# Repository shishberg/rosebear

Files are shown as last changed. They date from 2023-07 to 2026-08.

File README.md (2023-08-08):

# Rosebear

Rosebear is a 5x3+3 wireless split keyboard designed with [Ergogen](https://ergogen.xyz/). ZMK firmware is at https://github.com/shishberg/rosebear-zmk.

Thanks to [Ben Vallack](https://www.youtube.com/watch?v=M_VuXVErD6E) and [FlatFootFox](https://flatfootfox.com/ergogen-part5-kicad-firmware-assembly/) for the tutorials that made this even vaguely possible.

The assembled Rosebear split keyboard.

Screenshot of the Rosebear PCB in KiCad.

## Features
- Pretty aggressive stagger on the pinky column, and splay on pinky and ring columns
- Thumb cluster is waaaaay over there
- Direct pin wiring - no diodes
- Kailh choc switches - supports hotswap or soldered
- Bluetooth only (there aren't any pins available for a cable between the two sides)

## Lessons learnt
- Don't use a JST connector for the battery. Just don't. You don't need to. Crimping is fiddly as hell (I don't have a crimper and don't really want to buy one). Even if the battery comes with one, it's annoying as hell to unplug. Just solder the battery terminals on. If you want to replace or reuse the battery, unsoldering two wires is trivial.
  - I used a JST connector on the left board, but it was too hard so for the right board I just soldered the battery on. That was so much easier that it made me so mad that I unsoldered the connector from the left board, which was harder again; and then I soldered the battery in the wrong way around, which nearly burned out the nice!nano.
  - The picture above doesn't have a reset button because they haven't arrived yet.
- There _might_ be such a thing as too much pinky stagger. Or I might just need longer to get used to it.
- If you're not going to use a bottom plate, it would help to plan some empty spaces to put rubber feet.
  - PCBs don't come perfectly flat. If you're going to use rubber feet, you either need to use exactly three (and the triangle they form needs to cover all the keys or it'll rock when you press a key outside it); or you need to adjust their height (which I ended up doing with some ~1mm thick two-sided adhesive dots that I happened to have)
- I do like having the thumb cluster further out. I intended for the middle thumb key to be the "home" key (space and enter for me) and the one you have to stretch for can be something less common (esc and del). That's fine, but I should have made middle key 1.5u so it's easy to find.
- Choc pinks are so light they almost type by themselves under the weight of keycaps. I'd used dark yellows before and found them too heavy. Reds are about right.
- Choc keycaps could do with a bit of spacing between them vertically. Especially with very light switches, it's too easy to accidentally brush another key.

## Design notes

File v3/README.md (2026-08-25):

# rosebear v3 — direct-wired passive modules

Generates the five-board layout from `v2-p4-pod.md`: one ESP32-P4 pod plus four
passive modules (2× finger cluster, 2× thumb cluster), direct-wired, no matrix
and no diodes.

## Commands

```
baml test            # geometry golden test, ribbon and pod invariants
baml run build       # emit all five boards + DRC         -> ../output_v3/
baml run pinout      # the pod's GPIO assignment, for firmware
baml run pinout_leds # same, with per-key LEDs
```

Builds are deterministic: same config in, byte-identical boards out (UUIDs are
derived, not random).

## Layout

| file | contents |
|---|---|
| `geometry.baml` | `Vec2`, rotation primitive |
| `layout.baml` | `Point`, rotation stack, the zone walk |
| `config_rosebear.baml` | the 36-key layout, and the golden test |
| `features.baml` | variants, module partition, LED chain ordering |
| `ribbon.baml` | FFC pinouts — derived, never hardcoded |
| `netlist.baml` | components, nets, board outline |
| `route.baml` | copper on the key boards: escapes, fan-in, the LED chain |
| `pod.baml` | the pod board: module pinout, sockets, buttons, its own routing |
| `emit.baml` | `.kicad_pcb` emission |
| `build.baml` | entry points |

The config is BAML source, not YAML. There is no config parser and no schema
validation because the compiler does that job — `spread: 1.08 kx` was a string
mathjs evaluated at runtime; it is now `spread: 20.52`, and a typo fails to
build.

## Relationship to ergogen

The placement engine is a port of ergogen's `render_zone`, and
`config_rosebear.baml` carries a golden test asserting it reproduces ergogen
4.0.4's output for all 18 keys of a half to within 1e-6 mm (KiCad's own
nanometre resolution).

Ergogen remains a **dev-only** dependency, used solely as the test oracle via
`../v3/src/golden.ts`. Nothing at runtime depends on it, and it can be deleted
once you are happy with the port. The ~150 lines here replace 471 lines of
`points.js` + `point.js`; the difference is almost entirely ergogen's five-level
key inheritance, which the flat schema does not need.

## Ribbon widths are derived

`v2-p4-pod.md` works out "20-way" by hand (15 finger + 3 thumb pass-through +
ground + spare). That number appears nowhere in the code — `ribbon_signals`
computes it, and a test asserts the derivation reproduces the doc's 20 and 4.

Turning on per-key LEDs therefore costs one bool:

| | pod→finger | finger→thumb |
|---|---|---|
| base | 20-way | 4-way |
| `per_key_leds` | 25 → Molex 200528-0250 | 9 → 200528-0090 |

The growth is not just +1 data line: the doc's own rule ("that data line gets
its own grounded neighbor") is encoded, so each data conductor is flanked by
ground, and LED supply/return conductors are sized from the current budget.

### The cable reverses the pinout

A plain same-side FFC between two connectors that face each other joins the
contact rows by *position*: the conductors cannot cross, and the facing turns
one row around, so contact 1 of one connector lands on contact N of the other.
Nothing in the toolchain models the cable — the combined view joins nets by
name — so getting this wrong is invisible to DRC and costs a board spin. Two
things encode it:

- Each ribbon's `signals` list is the TO end's contact order; the FROM end
  (the pod for the pod links, the finger board for the thumb links) assigns
  its pads from the same list **reversed** (`from_end_signals`), rails and
  spares included.
- `evaluate.py` checks the physical mapping on `all.kicad_pcb`: for every
  link it pairs each contact with the far contact at the same position along
  the row and asserts they carry one net, and that the two rows line up
  (a flat cable cannot shear sideways — the panel slides the pod so the pod
  link's rows are level with the finger boards').

The audit that introduced this found all four links cross-wired end to end,
and the pod's two FFC connectors mounted with their cable openings facing the
pod's centre instead of the hand they serve (the Molex 200528 takes its cable
in over its own solder pads; the BackFlip actuator is at the rear).

## Placement

Two bugs found here were each enough to scrap a board, and both passed a visual
check and a clean DRC first:

- The KiCad `SW_Cherry_MX_*_PCB` footprints put their origin at **pad 1**, not
  the key centre — ergogen's own MX footprint puts it at the centre. Placing
  the origin at the key position shifted every switch by (−2.54, +5.08) mm.
- KiCad negates a footprint's stored rotation. Emitting `−r` (which reads
  correctly) turned every splayed key the wrong way; ergogen emits `+r`.

`netlist_test.baml` now checks the emitted key centres against ergogen's own
generated board, coordinate for coordinate, and checks the centre offset against
the installed `.kicad_mod` so a KiCad update can't move it silently.

## Status

`baml run build` — five boards, KiCad 10 format, per-key LEDs fitted (the
no-LED option is simply not populating them — same PCB), DRC clean apart from:

| board | violations |
|---|---|
| `finger_l` | **0** |
| `finger_r` | **0** |
| `thumb_l` | **0** |
| `thumb_r` | **0** |
| `pod` | 2 |

Unconnected items are **0 everywhere**.

- `pod`: 2 × `lib_footprint_mismatch` on the SKQG buttons. Deliberate: the
  emitter moves every reference designator to the fab layer, and the library
  copy of that part keeps its on silkscreen. Nothing to fabricate differs.
The two `pod` items are the only violations left.

For scale: the same DRC over the ergogen-generated v2 board reports **139
violations, 108 of them `copper_edge_clearance`** — copper too close to the
board edge. Drawing the outline around the finished routing avoids that class
entirely.

Board sizes: finger **156 × 104mm** (139cm² of actual outline), thumb
**66 × 51mm** (24cm²), pod **80 × 92mm**. The LED chain's halo reaches past
the keycaps to the sides and below, and the hull is drawn to hold it.

## All five boards in one file

`baml run build` also writes `../output_v3/all.kicad_pcb`: every board in one
file, in the positions they take on
the desk. The four key boards keep their own coordinates — they come from one
layout, so `finger_l` already knows where `thumb_l` is — and only the pod, which
has no place in the key geometry, is moved: centred between the hands, at the
height that puts its ribbon connectors' contact rows level with the finger
boards' — a straight cable cannot enter two rows at different heights.

It is not a fabrication panel. It is a viewing aid, and it earns its keep: a
board that is the wrong size, an outline that overlaps its neighbour, a
connector pointing away from the board it feeds are all obvious in the assembly
and invisible one board at a time. It found the outline overlap in *Known gaps*
within a minute of existing.

Shared net names — `GND`, the thumb pass-throughs, the LED rails — meet across
boards here, so KiCad's ratsnest draws the ribbons that are otherwise invisible.
Refs are prefixed with the board id, since five boards' worth of `SW1` in one
file is five different parts with one name. `emit_board` is `emit_panel` of a
one-board list, so the single boards and the combined view cannot drift apart.

## Routing

Not a general routing problem, and it doesn't get a general router. The
topology is a fan-in: each key has one net with exactly two pads -- its switch
pin and one ribbon contact -- and everything else is ground.

- **Ground is poured, not routed.** A zone on each side. The front is needed
  for the FFC connector's surface-mount mounting pegs, the back for everything
  else. `kicad-cli pcb drc --refill-zones --save-board` computes the fill, so
  the board that ships has the copper DRC actually checked.
- **Signals are river-routed.** Each key escapes sideways into a lane in the
  channel between its column and the next, the lanes run down the column to a
  line shared by the whole board, and each exit turns in to its contact.

  Planarity is a counting argument, not a search. Two chords joining two
  disjoint arcs of a convex region never cross exactly when the matching
  *reverses* the boundary order — first exit to last contact. `ribbon_signals`
  emits key signals in column order and *we choose the pinout*, so the exits
  are sorted; the connector's angle decides which end of it contact 1 sits at,
  and the angle that points the cable at the pod is the angle that satisfies
  the reversal. There is nothing left to choose, and nothing to search.
- **The outline is drawn last.** The placement guesses a hull from the keys and
  the connectors, which is all it knows; `enclose` then redraws it around every
  track and via the router actually laid. This is what took the last
  `copper_edge_clearance` violations off the boards, and it means a channel
  that reaches further than expected takes the board edge with it rather than
  running off it.
- **Pass-throughs use the back.** The three thumb nets cross the finger board
  without touching a switch on it. They drop through vias behind the connector
  contacts, run on B.Cu, and come back up; the pour parts around them.

Three constants are load-bearing and were found by measurement, not taste:

| constant | value | why |
|---|---|---|
| `LANE_PITCH` | 1.8mm | Two diagonals offset horizontally by *s* are only `s·cos θ` apart perpendicular. The widest fan-in here runs at 76° from vertical, so 1.0mm of lane pitch became 0.24mm of actual clearance -- a short. |
| `CONNECTOR_SIDE_OFFSET` | 8mm | How far outboard of the key field a finger half's connectors stand — the room the fan-in gets to spread into before it turns square onto the 1.00mm contacts. |
| the band rows | fitted | Each column's escape channel ends on its own exit line, one bus-gap short of its rows. `band_groups` stacks a group of rows per column, nearest-to-the-connector column deepest: a group sits as low as that column's own top signal pads and ground-stitch vias allow, or one bus pitch above the previous group's top, whichever is farther out. Nesting the groups keeps the joins planar -- a nearer column's rows turn off toward the connector before a farther column's rows pass over them, so the old single shared exit line (which held six rows of empty air over the middle column) is gone and the band hugs every column, not just the tallest. Only rows that actually ride the band get a slot, so the tail contacts of the 25-way link add no height. The LED chain stays out of the way entirely: its data head takes one extra row outboard of every group, and its column transitions thread the field on each key's north strip instead of crossing over the top of the columns. |
| finger connectors on the inboard edge | — | The pod sits between the halves, so both cables leave toward the middle rather than doubling back around the board. Turning the connector through a right angle also turns the fan-in: a straight run per net would approach contacts 1mm apart at a hundredth of that across the runs, so each net drops at its own exit x to its contact's row and turns in square. |

Freerouting was considered and isn't installed (no JRE, no jar). It would be
the wrong tool anyway: it can't exploit the fact that we own the pinout, and
its result isn't reproducible. The pod board is a different matter and will
likely want it.

## Per-key LEDs

The build fits an SK6812MINI-E under every key, reverse-mounted so it shines
up through a milled window. The chain is the only net on a key board that is not
a fan-in, and it drove the layer plan.

**The back becomes the supply plane.** 36 LEDs at 20mA is 720mA, which wants a
plane rather than a rail — and a plane is the only thing that reaches every LED
without a comb of stubs weaving between the hotswap sockets and the data chain.
The front stays ground. The cost is two vias per key: with the back given over
to the supply, the socket's ground terminal and the LED's both have to reach the
front pour.

**The chain runs in two shapes.** Within a column it goes on the *front*: out of
the LED's dout on the back, via up beside it, one lane up the column between the
switch's stabiliser hole and the previous column's channel, and back down beside
the next LED's din. Consecutive hops share that lane and never meet, because the
arrival row is past the departure row *in the direction the chain is
travelling* — so a column running down the board arrives above where it left,
and one running up arrives below. Getting that backwards is a 1.25mm overlap that
looks fine and shorts.

Between columns it goes on the *back*, because the front between two columns is
the first one's channel and cannot be crossed. The back can be, but only outside
the key field — so a transition leaves the column at whichever end the chain
reached, runs out past the last key, crosses at the extreme of the two staggered
ends, and comes back in. Boustrophedon ordering is what makes that work:
consecutive columns are always entered and left at the same end.

The chain's two link vias sit *in front of* the thumb pass-through band rather
than behind it — behind, they would have to cross every track in it.

**South of a key is one shared corridor.** The hotswap socket keeps all its
hardware north of its key's centre, so the only clear lane across a key runs
south of the LED — and three things want it: the under-the-bottom crossing
between two columns, the tail on its way out, and the LED's own ground drop.
The drop therefore goes straight down off the ground pad and stops
(`LED_GND_VIA`), instead of hooking out across the corridor; the crossing and
the tail then share the row (`LED_UNDER_Y`). The old deep crossing row is
unusable anyway: the thumb board's notch is cut out of the south edge, and a
crossing that dropped past it fell off the board.

Which row the tail leaves on depends on which way out it goes, because the two
sides of a key close off at different depths — the din stub comes down to the
elbow on one side, the next socket's ground hook reaches up past the exit row
on the other. The footprints do not mirror, so that is a per-hand choice, not a
mirrored one.

**The head runs in the column's frame, not the board's.** It leaves the pod
link on that contact's own bus lane, crosses the empty north on the back, and
comes down the outside of the first column. The columns are splayed: a plain
vertical drop at the entry point's x walks across the key frame as it climbs —
into the socket pads on one hand and the transition lanes on the other — while
a line parallel to the column holds its offset all the way. That line cannot
reach the north row, which is up where the hull narrows into its corner, so the
run turns onto it on a short diagonal.

**The thumb cluster gets its own chain shape.** Its three keys are one column
each on an arc, so neither the along-a-column nor the between-columns shape
fits. Each hop runs straight from the source's dout to an approach point out
along the destination's din row; when the exit corner and the travel direction
disagree the hop swings around the source's hardware, and on the mirrored hand
that swing goes over the front, because two back-side swings fence each other
in. The chain starts at the far key so its head enters without crossing the
cluster.

**The pass-through strip nests by travel distance.** Each pass lane drops to
its own row of the strip and then runs along it to its contact; a lane that
crosses the whole strip has to pass under every vertical dropping into it, so
it takes the deepest row and the shortest hop the shallowest. Which end of the
thumb link the keys sit at depends on the hand *and* on how wide the link got,
so the order is read off the pads rather than assumed. The chain's own link
contact can land in the middle of that band — the lanes are placed off the pod
link and the contact off the thumb link — and where it does, its drop leans out
to the far side of the band before diving.

**An LED stores the negation of its key's angle.** It is on the back, so KiCad
mirrors it: the stored angle is applied to coordinates that have already been
flipped about the x axis. Store the key's own angle and the part's pads swing
away from the key's axis at *twice* the rate — invisible on a finger column
splayed 5°, and by the time the 1.5u thumb key reaches 60° the data pad has come
right back round onto the switch's 4mm stem hole, 2.37mm from a hole with a 2mm
radius. That one sign was most of the thumb boards' violations. There is a test
that pins every LED pad's position in its key's frame across all 36 keys.

## The pod

The module is a WT9932P4-TINY: 68.59 × 28mm, two 27-pin rows 2.54mm pitch and
**25.40mm apart**, Ø1.05mm holes. Measured out of `WT9932P4-TINY_3D_V1.1.step`
rather than read off a drawing; two `PinSocket_1x27_P2.54mm_Vertical` seat it
exactly. Pinout from `..._pinout_V1.3.1.png`, cross-checked against J6/J7 in
`..._SCH_V1.3.pdf`.

Mounted long-axis up with the USB connectors at the far edge, which turns it 180°
from the datasheet drawing: the row drawn on the right lands on the left, and
the pin drawn at the top becomes pin 1 at the bottom, nearest the connectors.

### Why it routes without a search

Same reason the key boards do, one layer deeper:

- **Each hand is served by the socket on its own side.** The two fans never
  meet and neither has to cross the module. Both hands need 19 pins with the
  base variant and 20 with LEDs; the sockets carry 26 and 21 GPIO.
- **The ribbons leave sideways**, left and right, so a connector's contacts
  stack *up* the board in the same axis as the pins they serve: a 27-pin column
  at 2.54mm against a 20-contact column at 1.00mm, offset in x. Every net is one
  horizontal out of the socket, one vertical along a lane, one horizontal into
  its contact — no diagonals at all.
- **The fan splits into two halves that share one set of lanes.** The contacts
  are packed tighter than the pins, so pins above the middle reach *down* to
  their contacts and pins below reach *up*. Within a half, the pin whose
  contact is furthest away takes the outermost lane; that is enough to make
  each half planar, and the halves never overlap in y, so they can reuse the
  same lanes. The channel is therefore only **half as wide as the ribbon**.

  The proof is two lines. For nets *i* and *j* of the same half, in ascending
  order of height, a crossing needs one net's horizontal to meet the other's
  vertical, which happens only if q*ᵢ* lies between p*ⱼ* and q*ⱼ*. In the half
  that reaches down q*ⱼ* > p*ⱼ* > p*ᵢ*; in the half that reaches up
  q*ᵢ* < p*ᵢ* < p*ⱼ*. Neither can. `pod_test.baml` checks the monotone pairing,
  the half-widths and the disjointness, and then checks planarity
  geometrically anyway.

The connectors sit on the left and right edges, so the board is **74mm wide and
the finger ribbons leave sideways**, one per hand, toward the boards they serve.
The mounting holes moved to the strips past each end of the module — the sides
are escape channel for most of the board's height, and those strips are also the
only places a screw head clears the module, which stands 8mm off the board on
its headers.

The buttons and the LED supply are the exceptions, and they go on the back: the
front between the sockets is pour and the front outside them is the channels.
Both use the same discipline — come up a clear lane, turn in square at the
target pin — because approaching a column of 2.54mm through-holes on a diagonal
shaves every pad it passes. Two buttons sharing a socket nest, and the staircase
runs the *other* way there: they sit inboard, so the lane nearest the pin column
is the one every other run has to cross, and it drops to the back furthest down
the board. That is the sort of argument that reads fine and is wrong half the
time, so `pod_test.baml` checks planarity geometrically — every pair of tracks
on a layer, both variants — rather than trusting the reasoning.

### Spending the GPIO

`v2-p4-pod.md` says pin scarcity doesn't exist here. True, but by a narrower
margin than it reads: 47 pins reach the headers and only **33 are unencumbered,
against 36 keys**. So some has to be spent, and `pin_cost` orders the
concessions rather than letting position decide:

| cost | pins | what it costs |
|---|---|---|
| 1 | IO39/40/43–48 | needs `LDO_VO4` enabled — free in practice, there is no SD card |
| 2 | IO37/38 | the UART0 console; USB-CDC still works |
| 3 | IO2/3/4 | hardware JTAG |
| 4 | IO36 | strapping — a key held at boot changes boot mode |

The assignment spends five SD-domain pins and one UART pin, and **leaves JTAG
and the strapping pin alone**. Both buttons are on the left socket rather than
one per side: buttons are ranked across the pair, and with LEDs fitted the right
socket has exactly one pin spare — the strapping pin. Ranking matters twice
over; taking spares in header order also put a button on JTAG while three SD
pins sat unused beside it.

IO51 already drives an on-board RGB LED and IO35 is already the BOOT button;
neither is broken out, so both come free.

`baml run pinout` prints the assignment with the concessions marked.

### Known gaps

- **The boards run a 0.2mm copper-to-edge rule.** Not our routing: the
  KiCad `SK6812MINI-E_..._ReverseMount` footprint mills the window the light
  comes up through and puts the LED's own four pads 0.239mm from the edge of
  it. `build.baml` writes a `.kicad_pro` per board carrying the rule. Worth
  checking against a fab before ordering.
- **Connector placement is derived, not designed.** Every connector now points
  its cable at the board it feeds, and that single rule fixes the rest: the pod
  link stands on the inboard edge level with the switches, cable out toward the
  middle of the keyboard; the finger board's thumb link sits below the innermost
  column facing down, where the cluster is; the thumb board's own connector sits
  above its keys facing up. Turning a connector also decides which end of it
  contact 1 is at, so the pinouts follow from the placement rather than being
  chosen — see *Routing*. What is still undecided against the case is how far
  outboard each one stands.
- **The finger and thumb outlines overlap.** `../output_v3/all.kicad_pcb` puts
  all five boards in one file at their real relative positions, and shows that
  the finger board's convex hull sweeps over two of the three thumb switches:
  the thumb cluster tucks in under the splayed columns, and a hull drawn round
  the finger keys covers it. Two separate coplanar PCBs cannot do that. The
  finger outline needs clipping back around the cluster, which makes it the
  first non-convex outline in the pipeline.
- **The pod board is generated but hand-designed.** Nothing about it falls out
  of the key layout, so unlike the key boards its geometry is chosen rather than
  derived. The one thing that *is* derived is the part that matters: which GPIO
  each key lands on. See "The pod" below.
- **Choc (PG1350) is not available.** Stock KiCad has MX only; Choc would need
  a third-party footprint library registered.
- **Panelization is not attempted.** Deferred deliberately.

## Hotswap

Switches are not soldered in. Each key gets a **Kailh CPG151101S11 socket on the
back**, and the switch drops into it.

KiCad ships no hotswap land pattern, so `footprints/gen_hotswap.py` generates
one: copper from ergogen's own `mx.js` (vendored in this repo under
`node_modules/`, which is where the community-standard numbers live), outlines
from KiCad's `SW_Cherry_MX_*_PCB`, and the origin moved to the stem hole — which
is the frame both sources already quote their numbers in, so
`SWITCH_CENTRE_IN_FOOTPRINT` is now zero. `build.baml` writes an `fp-lib-table`
beside the boards so DRC can resolve `rosebear:`.

It is a routing decision as much as a mechanical one, and it changed three
things:

- **A key's two terminals are surface pads on the back**, not through-holes. So
  an escape cannot start on the front: it leaves the socket on the back, crosses
  to the channel, and vias up at the innermost lane. Everything downstream is
  unchanged.
- **The ground pours stopped being connected to each other.** A soldered switch
  is two plated holes, one of them ground, and those alone stitched front to
  back at every key. A hotswap key has no plated hole at all, so without a
  deliberate via per key the two GND zones are two islands of the same net —
  which DRC reported the moment the footprint changed.
- **The back got crowded**, which is what forced the LED layer plan below.

## The MCP's role

Board files come from `baml run build` — reproducible, no agent required. The
KiCad MCP is for the judgement work: looking at the board, DRC triage, routing,
and connector placement experiments. Decisions made there get committed back
into the BAML config as explicit values, so the boards stay regenerable.

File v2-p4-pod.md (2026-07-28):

# v2 concept: ESP32-P4 pod + passive modules

Design sketch from a brainstorm that started as a GPT-autocomplete keyboard
(see `mezzacomic/docs/keyboard-v2-esp32p4.md` for the model/compute side and
the autocomplete interaction sketch) and turned into a physical architecture.
This is a **different path entirely** from `v2.md` (which was the tail end of
an earlier brainstorm) — see "Relation to v2.md" below.

## Concept

One smart **pod** in the middle; everything else is passive copper.

- **Pod:** ESP32-P4 dev board + OLED + status LED + the model. Free-floating,
  placed wherever gaze wants — solves OLED centrality without a unibody.
- **2× finger cluster:** 15 keys each, fully passive PCB (switches only, no
  diodes, no components).
- **2× thumb cluster:** 3 keys each, passive, **daisy-chained off its finger
  board** (short ~10cm ribbon hop) so it can be angled independently without a
  home run to the pod.
- **Ribbons:** FFC. Pod→finger 20-way each (15 finger + 3 thumb pass-through +
  ground + spare); finger→thumb 4-way.

5 boards, 4 ribbons. Rare but not extreme: commercial boards can't ship this
(cable management, support burden); as a personal ergogen project it's the
"adjust everything until it's right, then it's one firmware" design. Every
module is independently reprintable — new thumb angle = one small case.

## Platform: WT9932P4-TINY

ESP32-P4: dual RISC-V @ 400MHz, FPU, PIE 128-bit SIMD (int8-friendly), 768KB
SRAM, two USB OTG controllers. The WT9932P4-TINY board specifically: both USB
controllers on real Type-C connectors, 16MB flash / 32MB PSRAM, RGB LED,
boot/reset, ~50 GPIO, 69×28mm, none of the C6/ethernet/camera baggage of other
P4 dev boards.

16MB flash is not the model-size constraint — generation is
memory-bandwidth-bound (every token reads every weight; PSRAM ≈100–200MB/s, so
a 15MB int8 model caps around ~10 tok/s regardless of SIMD). A model sized for
snappy autocomplete is well under 16MB.

Verify on schematic before ordering (for the MITM/host use of the second
port): VBUS routing *out* of the host-side port, and Rp CC pull-ups for host
role (moot with a USB-A keyboard + adapter).

## Direct-wired, not matrix

36 keys, ~50 GPIO — the only argument for a matrix is pin scarcity, which
doesn't exist here.

- Passive boards stay *actually* passive (matrix puts a diode per key back on
  every module).
- 20-way vs 9-way FFC is the same cable family and price class.
- No driven scan edges crossing ribbons; per-pin interrupts instead of a scan
  loop; trivial wake-on-any-key — pleasant when the CPU's day job is
  inference.
- NKRO by construction, firmware is "read 36 inputs".
- RMK supports direct-pin scanning.

Escape hatch: a future module that busts the GPIO budget (numpad, per-key RGB)
gets a matrix *on that module only*; nothing here forecloses it.

## Ribbons: interference and protection

Switch lines are quasi-DC — no length limit at desk scale (30–50cm fine). The
one real mechanism is noise pickup on high-impedance open-switch lines.
Layered defenses, in order of need:

1. Firmware debounce (RMK default: integrating, 20ms) — a glitch must
   persist milliseconds to register. Eats nearly everything.
2. Ground conductor per ribbon.
3. External 4.7–10kΩ pull-ups at the pod (internal ≈45kΩ) — colocate with the
   ESD resistors.

**ESD is the bigger real risk:** 36 unbuffered MCU pins on human-adjacent
connectors. Series ~100Ω on every line at the pod, TVS on ribbon headers —
pennies, non-optional.

**Keep fast signals off the ribbons.** OLED (I2C) and LED live on the pod, so
nothing with µs edges runs alongside high-Z switch lines. If a future rev
wants per-cluster LEDs, that data line gets its own grounded neighbor.

## Geometry and tenting

Get splay/angles right first **as though it's a unibody** — the ribbons are
not a tenting mechanism. No torque on connectors; tenting is only rotation in
the axis of the connector. 20-way and 10-way ribbons sit differently on the
desk and twist differently; the design assumes neither is asked to twist.

## Relation to v2.md

`v2.md`'s dual-mode design (BLE portable mode, nRF52840 per half, battery,
hardware-gated LED rail) is a different path from a different session, and
this design deliberately doesn't attempt it:

- ESP32-P4 has no radio (hence all the dev boards pairing it with an
  ESP32-C6). Wireless would mean a companion chip via ESP-Hosted.
- Passive modules preclude BLE split entirely — there's nothing on the far
  side to radio with.
- **Ruling: wired-only is fine.** This thing runs a 400MHz dual-core doing
  continuous inference; it was never a battery keyboard anyway.
- Per-key RGB (v2.md home mode) conflicts with the keep-fast-signals-off-
  ribbons rule; possible later but needs its own conductors and the ESD/noise
  story reworked.

## Open questions

- RMK (or bare Embassy + esp-hal) maturity on ESP32-P4 — spike before any PCB.
- WT9932P4-TINY schematic checks (VBUS out, CC pull-ups) if the MITM spike
  happens on the same board.
- FFC connector selection: locking, mounting orientation, insertion cycles.
- Pod enclosure: dev-board-in-a-case vs eventual carrier PCB.

## Starting point if picked up

1. P4 dev board: port the mezzacomic `pico-gpt` engine, benchmark PIE int8
   matmul — one number sizes the model.
2. RMK/Embassy HID spike on the P4.
3. Ergogen: current 36-key layout re-cut as 4 passive modules + pod, angles
   locked as-if-unibody.

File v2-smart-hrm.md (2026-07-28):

# v2 concept: learned homerow mod disambiguation

Companion to `v2-p4-pod.md`. The version of "spend the P4's compute on
typing" that earns its keep: decide tap-vs-hold for homerow mods from the raw
keyup/keydown stream, personalized to how I actually type.

## Problem

Homerow mods trade a dedicated mod key for an ambiguity: every home-row press
must be classified as *letter* or *modifier* after the fact. Fixed heuristics
misfire on exactly the patterns fast typing produces — rolls (`s`→`a`
overlapping reads as Shift+A → `A`), quick mod chords mid-burst, timing that
drifts with fatigue. Years of tuning across QMK/ZMK/RMK hasn't closed the
gap, because the heuristics see two or three scalar features and the intent
signal is richer than that.

## State of the art

All shipping solutions are hand-tuned rules over a handful of features:

| Mechanism | Signal | Firmware |
|---|---|---|
| Tapping term | hold duration vs threshold | all |
| Quick tap (`quick-tap-ms`, `gap_timeout`) | re-press of the same key within a window | all |
| Permissive hold / `balanced` | nested press+release inside the hold | all |
| Hold-on-other-key-press | any second press | all |
| Positional (`hold-trigger-key-positions`; Chordal Hold, QMK 0.28; `unilateral_tap`) | position set / handedness of the chord | ZMK / QMK / RMK |
| Prior idle (`require-prior-idle-ms`; Flow Tap, QMK 2025; `flow_tap`) | idle gap before the press | ZMK / QMK / RMK |

Positional + prior-idle (urob's "timeless" config) is current best practice
and still misfires on same-hand mod chords and fast opposite-hand rolls — the
cases position can't separate. No shipped firmware learns from the user or
uses text context. That part is open territory.

## What's been tried here

Three firmwares, one layout: Colemak-DH, C-A-S-G inward (pinky Ctrl, ring
Alt, middle **Shift**, index GUI), thumb layer-taps. Shift-on-middle carries
the shortest timing in every config — it's the chronic misfire
(`shifted_tap` in the analyzer's taxonomy).

- **ZMK** (`rosebear-zmk`, stale, origin of the layout): tap-preferred,
  150ms short (S/E) / 200ms long, `require-prior-idle` 100/150ms. No
  positional hold-tap.
- **QMK** (`rosebear-qmk`): per-key terms (140ms S/E, 200ms others, 160ms
  thumbs), vendored Achordion (since deprecated upstream) with a custom
  chord rule — same-hand non-thumb press within 180ms cancels an S/E hold,
  thumb keys exempt — plus per-key streak windows (100–150ms) approximating
  prior-idle. The config predates QMK's native Chordal Hold and Flow Tap
  (both 2025) and enables neither.
- **RMK** (`rosebear-rmk`, daily driver = `variants/rosebear-direct`):
  flow-tap (100ms prior idle) + permissive hold, 120ms S/E / 180ms home /
  140ms thumbs, `unilateral_tap` off everywhere. Runs against a local RMK
  fork carrying an in-progress repro test for a tap-hold buffering bug: fast
  taps during a layer-tap hold emit mixed base+layer output in one
  configuration — normal mode + flow-tap off + 140/180ms timeouts (12 of 144
  permutations, all don't-care variations of that one setting). The root
  Corne config's long 200/250ms profiles work around it; the daily driver
  avoids it via permissive-hold + flow-tap.

Two conclusions. First, the deployed configs predate the 2025 generation of
heuristics — native Chordal Hold and Flow Tap are enabled nowhere — so the
modern heuristic ceiling is **unmeasured**, not exhausted. Measuring it is
the mandatory control arm (option 0). Second, the data pipeline already has
a prototype: `rosebear-qmk/keyboards/crkbd/keymaps/rosebear/tools/` has a
raw HID event logger (`hid_log.py`, `decode_hid_log.py`) and
`analyze_holdtap_session.py`, which correlates firmware mod/layer state
against Monkeytype browser keystrokes and labels every hold-tap decision
`true_positive` / `false_positive` / `false_negative` / `shifted_tap`. That
is capture plus drill-labeled ground truth, working today.

## Reframing: classification with a deadline

Tap-hold resolution is an online classification problem: at each event
(press, release, timer tick) estimate P(hold | evidence so far) and
**commit** when confidence crosses a threshold or a deadline expires. Every
existing heuristic is a special case with a hand-written decision boundary.

Misfire classes are named intent→resolution throughout: **tap→hold** (meant
the letter, got the modifier) and **hold→tap** (meant the modifier, got
letters).

Structural constraints:

1. **Commit-only.** HID can't unsend. Once a letter is emitted or a modifier
   applied, the decision is final. (Host-side rewrite is an aggressive
   escape hatch — see open questions — the core design assumes no
   retraction.)
2. **Asymmetric loss.** tap→hold fires a shortcut (Ctrl+A, Cmd+W) —
   potentially destructive. hold→tap emits garbage text — visible and cheap
   to fix. Under uncertainty, resolve tap. Good heuristics already encode
   this bias; a classifier makes the loss ratio an explicit tunable.
3. **Asymmetric observability.** hold→tap leaves a crisp correction
   signature in the keystream (`s/` → 2× backspace → `?`). tap→hold leaves a
   weaker one — the *recovery* is visible: undo chords, Escape, or a
   backspace burst shortly after a hold resolution. Labels for the
   destructive class are scarcer and noisier; see labeling.

## Latency

Single-digit-ms applies to *added* latency, against the real baseline:

- A tap commits at **release** (i.e. after the hold duration, ~50–90ms
  mid-flow) — or at **press** under flow-tap, which fires whenever the
  preceding gap is short. Fast typing already gets instant taps today.
- A hold commits at the tapping term, or earlier on a disambiguating event
  (permissive hold).

The classifier's latency claim is narrow: it generalizes flow-tap's early
commit from one bit (prior gap) to a learned confidence over the full signal
inventory, so more presses commit instantly. The cost is explicit: each
commit-at-press forfeits the release-timing evidence that today arrives
before commit, and constraint 1 makes the resulting hold→tap misfires final.
The confidence threshold prices that trade; it is a tunable, not a free win.

Decision-time compute at 400MHz: feature extraction ~µs, int8 classifier
(<10k params) 10–100µs, n-gram lookup ~ns. All trivially inside budget.

The LM prior never runs at decision time. After each committed character a
background task advances the model (incremental KV cache — the autocomplete
machinery from `keyboard-v2-esp32p4.md`) and leaves a next-char distribution
in RAM (token→char via a precomputed first-char table). Two honest caveats:
BPE tail instability means 1–2 forward passes per character, and bursts have
30–60ms inter-key gaps — exactly the events this design targets — while a
forward pass costs 10–100ms. The prior is stale precisely when it matters
most, so the classifier treats it as best-effort and falls back to the
n-gram, which is always fresh. Whether the LM ever adds value *in time* is
an open question replay can answer.

**Timestamp fidelity.** RMK's default debouncer is deferred and integrating
(1ms sampling, 20ms window) over a polled scan loop; per-pin interrupts with
an eager debouncer would be new code, and mechanical bounce sets a ~1ms
floor regardless. The discriminating overlaps are tens of ms, so 1ms
resolution suffices. The pod design's real capture win is elsewhere: all 36
keys on one controller means no split-link timestamp skew (see capture).

## Signal inventory

Features available at decision time, in order of expected value:

- **Timing:** hold duration so far; overlap duration with subsequent press;
  inter-key intervals for the preceding ~5 events; idle gap before the press
  (continuous generalization of prior-idle).
- **Identity/geometry:** which key; which subsequent key; same-hand vs
  opposite (the one bit the positional heuristics use); finger assignment;
  roll direction (inward rolls are the classic misfire).
- **Release ordering:** rolls release in press order; deliberate chords hold
  the mod past the nested key's release (permissive hold, generalized to a
  continuous feature).
- **Rhythm state:** EMA of recent inter-key interval (burst vs deliberate);
  time since last correction.
- **Text context:** P(literal continuation) from char n-gram or LM — after
  `discu`, `s` is a letter, and no shipping firmware knows it; `s` after a
  2s idle at a line start is Ctrl+S territory.

## Options

Composable; the expected path is 0 → A → B → D, with C, E, F as measured
branches.

**Option 0 — modern heuristics, properly.** Enable the 2025 generation and
measure it: Chordal Hold + Flow Tap in QMK — `get_chordal_hold()` is
signature-identical to the existing `achordion_chord()`, so the custom
same-hand rule ports mechanically — and flow-tap is already live in RMK.
This is the control arm; no claim of "smarter" means anything against
anything less.

**Option A — offline-tuned heuristics.** Keep the heuristic form, fit the
parameters (per-key terms, idle thresholds, chordal exceptions) by replaying
logged typing through candidate configs and minimizing weighted misfires. No
runtime ML, no latency risk, deployable on any firmware including the
current board. Replay decides how much of the win this captures; it requires
the data pipeline, which is the real asset anyway.

**Option B — feature classifier.** GBDT or tiny MLP over the signal
inventory (minus LM), confidence-threshold commit with deadline fallback.
Trained offline on logged data, quantized into flash. The first rung that
can express "this same-hand roll shape at this speed is always a tap *for
me*".

**Option C — sequence model.** Small GRU/TCN over the raw event stream,
learning features implicitly. More data-hungry, harder to inspect, and the
handcrafted features already encode most known structure. Only worth it if B
plateaus measurably below the labeled-data ceiling.

**Option D — language prior.** Add the precomputed next-char distribution as
a classifier feature. Start with a char n-gram table (KBs–MBs, built from my
own prose + code corpora); the full pico-gpt engine is the same interface
with better tail behavior. Measure the n-gram-vs-LM gap in replay before
paying the engine-port cost. This is the P4-only option — nothing else here
strictly needs 400MHz.

**Option E — online adaptation.** On-device mispredict detection (correction
signatures) nudges thresholds or per-key priors between offline retrains.
Bounded adaptation (clamped threshold offsets, not weight updates) keeps a
bad week of data from bricking muscle-memory trust.

**Option F — generative typing model.** Drills produce aligned (target text,
event stream) pairs; fit a model of *my typing given intent* — next key
event and its latency conditioned on prior events and the text being typed.

The cheap rung is **mutation**: keep real logged streams, estimate
per-key/per-transition latency variance, and jitter timestamps within it —
order swaps included, which is exactly the misfire-generating mechanism.
Intent is pinned by the original stream, so this is label-preserving
augmentation that manufactures near-boundary variants of real events with no
model fitting beyond variance estimates. Do this before the full model.

The full model has two uses:

- *Synthetic training data.* Sample unlimited labeled event streams,
  including the hold-intent cases natural data barely labels (closes the
  observability asymmetry from the generator side). Sim2real is the risk:
  misfires live in the tails of the timing distribution and generative
  models smooth tails, so a classifier trained purely on samples learns the
  simulator's boundary. Synthetic pretrains and augments; real data
  fine-tunes; evaluation is real-only.
- *Direct Bayes classifier.* A calibrated generative model classifies
  without a discriminative stage: commit on the likelihood ratio
  P(events | tap) : P(events | hold) × text prior. Subsumes option D — the
  text prior and the timing model become one scoring function. Host-side
  first (it's the replay harness's scorer); on-device only if a distilled
  version fits the µs budget.

## Data pipeline

The pipeline is the project. Every option including "just tune the
heuristics" gets its value from it.

**Capture.** Firmware streams raw events — key id, edge, event-time
timestamp, plus its own decisions and their timing — over a side channel
(raw HID or CDC) to a host logger. Two requirements the prototype teaches:
logging runs queued off the scan/decision path (`hid_log` currently sends
synchronously inside the event hook, perturbing the timings it measures),
and timestamps are taken at event time (it already does this — preserve it).
Split-link skew is the other trap: both capture candidates are splits (QMK
stamps peripheral-half events at master read; the RMK daily driver is a BLE
split), so cross-hand ordering — the top feature — carries a systematic
ms-scale one-sided skew. Log it, estimate it, treat cross-hand overlap
features accordingly; the single-controller pod removes it entirely.

**Labeling.**
- *Correction mining (hold→tap):* resolved tap followed within a short
  window by backspaces and a retype consistent with the mod interpretation →
  high-precision label.
- *Undo mining (tap→hold):* undo chords, Escape, or a backspace burst
  shortly after a hold resolution → the scarce destructive-class labels,
  same mechanism, no host access needed.
- *Heuristic consensus:* events where all baseline algorithms agree and no
  correction follows → weak labels, huge volume. Most typing is unambiguous;
  the classifier must first not break the easy 99%.
- *Calibration drills:* typed exercises with known intent → gold labels,
  distribution-shifted from natural typing. Evaluation more than training.
  `analyze_holdtap_session.py` already does this against Monkeytype,
  including the `shifted_tap` class.
- *Host-side ground truth (optional):* a helper using accessibility APIs
  sees focused-app and actual text effects, closing the tap→hold
  observability gap fully. The Monkeytype analyzer is a scoped version of
  this; generalizing it is a keylogger-adjacent decision taken separately.

**Replay harness.** Drive the *real* resolvers, not models of them: the RMK
fork already has a test harness feeding timed key sequences to the actual
keyboard core and asserting HID reports (`tests/common/`, three large morse
suites), and QMK has a native tap-hold test harness. Hand-modelled semantics
only for engines out of reach. Feed logged streams through candidates —
option 0 configs, A sweeps, B/D/F scorers — and score per-class misfires and
commit-latency distribution against labels. All tuning and all claims happen
here; firmware receives winners.

**Metrics.** Per-class misfire rates (tap→hold weighted ×N), commit-latency
distribution vs baseline, corrections per 1000 decisions over time. Two
integrity rules: the destructive class is only observable via undo mining,
drills, or the host helper — report it separately, never blended into a
single rate; and corrections are also a label source, so headline evaluation
runs on held-out drill data, not on the signal that generates training
labels.

## Deployment shape

A decision engine at RMK's tap-hold resolution point. RMK has no pluggable
behavior trait — morse resolution is inline in the keyboard event loop — so
this is a fork of that path; the fork already exists locally for the
buffering repro. Deferred emission with a hard deadline at the configured
tapping term bounds worst-case latency; a passthrough mode (classifier off →
stock resolver) is the safety switch, and equivalence to stock is claimed
only for that mode. Weights live in flash and stay hot in SRAM; the
LM/n-gram task on core 1 owns the PSRAM traffic, and the decision path
touches none of it at decision time.

## Open questions

- **Deferred emission in RMK.** The buffering repro says the event-queue
  semantics need care; does RMK's buffer shape support a resolver that holds
  events until commit, or does that path need restructuring first?
- **Destructive-class labels.** Is undo mining + drills enough signal for
  tap→hold, or does honest training data require the host-side helper?
- **Data volume and drift.** How many hours of logging before B beats
  tuned-A in replay? Does timing drift (fatigue, day-to-day) demand E, or is
  a periodic offline retrain enough?
- **n-gram vs LM.** Does the LM prior ever arrive in time during bursts —
  the events that matter? If not, option D *is* the n-gram table.
- **Corpus split.** Prose and code have different char statistics and
  different mod usage (`s/` is sed, not a typo). One model with a context
  feature, or per-mode models switched by layer?
- **LM arbitration.** Autocomplete generation (`keyboard-v2-esp32p4.md`) and
  the per-char prior are two continuous consumers of one engine and one
  PSRAM bus; who yields, and when?
- **Retraction mode.** Host-side rewrite means buffering and re-sending a
  run of output, not a single backspace — and it's catastrophic in password
  fields and non-text contexts the keyboard can't see. Default no; is there
  a safe opt-in subset?
- **Scope.** Homerow mods and thumb layer-taps share the engine (same
  ambiguity, same features). Combos are a different shape — a decision over
  a key *set*, not a per-key label — and stay out.
- **Privacy.** Capture logs are keylogs of my own machine. Retention,
  password-entry exclusion (a pause-capture key?), and whether logs ever
  leave the box.
- **Context breaks.** Mouse edits and app switches invalidate the LM context
  (accepted as approximate in the autocomplete sketch); the prior feature
  degrades to n-gram/uniform when stale.
- **Felt latency.** Does earlier confident commit produce a *perceptible*
  improvement, or only benchmark deltas? Blind A/B once a replay winner
  ships.

## Starting point if picked up

1. Capture: extend the `hid_log` pipeline into an always-on logger, queued
   off the scan path, on the daily driver. Weeks of data cost nothing.
2. Replay harness around the real RMK/QMK resolvers; measure today's actual
   misfire rate and latency. `analyze_holdtap_session.py`'s taxonomy is the
   seed. Everything else is judged against this number.
3. Option 0 on-board and in replay: native Chordal Hold + Flow Tap, custom
   chord rule ported to `get_chordal_hold()`. The modern-heuristic ceiling,
   measured.
4. Option A sweep in replay; backport the winner to the current board.
5. Option B, then D (n-gram first), each shipping only on beating the
   incumbent in replay by a margin that survives the deadline constraint.

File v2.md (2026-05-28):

# Custom Dual-Mode 36-Key Split Keyboard: Hardware/Firmware Handoff

## Project goal

Build a fully custom **36-key split keyboard**, with **18 keys per half**, that can operate in two distinct modes:

1. **Home / desk mode**

   * USB connection to the host computer.
   * Wired connection between keyboard halves.
   * Per-key RGB LEDs enabled.
   * Battery drain is not a concern because the keyboard is externally powered.

2. **Office / portable mode**

   * Bluetooth/BLE connection to the host computer.
   * BLE connection between the two keyboard halves.
   * Per-key LEDs disabled.
   * No external cables between host or halves.
   * Battery life matters.

The keyboard does not necessarily need seamless hot-switching between modes on day one. The priority is to avoid a hardware design that makes either mode impossible later.

A reset/reboot to change modes is acceptable initially. Runtime mode switching can be treated as a later stretch goal.

## Layout assumption

The keyboard is a **36-key split**, with **18 keys per half**.

This probably does not materially change the MCU choice, but it helps guide the build:

* Low matrix pin pressure.
* Small PCB per half.
* Easier to reserve spare GPIOs.
* Lower LED count than larger keyboards.
* More realistic battery operation in portable mode.
* More room in the pin budget for UART, cable detect, LED control, battery sense, and debug features.

A typical matrix might be something like:

* 3 rows × 6 columns per half, or
* another 18-key-per-half arrangement depending on physical layout.

Because the layout is small, do not aggressively optimise away useful GPIOs. Prefer a simple, debuggable matrix and preserve spare pins.

## Recommended platform

Use **nRF52840 on both halves**.

This remains the recommended hardware platform because it gives the best long-term balance:

* Native USB device support.
* Strong BLE support.
* Good fit for battery-powered keyboards.
* Mature keyboard ecosystem.
* Enough GPIO for a 36-key split plus LEDs, UART, cable detect, and debug.
* Suitable for custom Rust/Embassy/RMK work.

However, RMK’s current stock support has an important limitation:

> RMK appears to support BLE split on nRF52840, but stock serial split code generation currently appears to be implemented for RP2040, not nRF52840.

This means nRF52840 is not the lowest-effort stock-RMK platform for wired serial split today. It is still a good hardware choice if we are prepared to implement or adapt nRF52 full-duplex UART serial split support in RMK.

## Key RMK support finding

RMK’s documentation describes wired split in generic serial terms, but the current macro implementation appears to panic for non-RP2040 serial split initialisation with an error like:

```rust
panic!("Serial for chip {:?} isn't implemented yet", chip.series)
```

For nRF52840, this means:

| Mode | Stock RMK confidence |
| --- | ---: |
| BLE host + BLE split | High |
| USB host + BLE split | High |
| USB host + wired serial split | Not currently stock-supported |
| One firmware that auto-selects BLE or serial split | Custom work |
| Full-duplex UART serial split after RMK changes | Plausible |
| One-wire/TRRS-style serial split | Avoid for this project |

The project should assume that **nRF52840 wired serial split requires custom RMK work**.

## Why full-duplex UART changes the risk

The earlier concern came partly from TRRS-style keyboard conventions, where the inter-half link is often a constrained single-wire serial connection.

For this project, we are designing the hardware from scratch. Therefore, we should avoid single-wire serial entirely and use **full-duplex UART** between halves.

Recommended wired split signals:

```text
central TX  → peripheral RX
central RX  ← peripheral TX
GND         ↔ GND
wired power → peripheral wired/LED rail
```

This avoids:

* Single-wire bus arbitration.
* Half-duplex direction control.
* RP2040 PIO-style tricks.
* Open-drain signalling complexity.
* TRRS hot-plug shorting assumptions.
* “Which side is driving the line?” bugs.

The RMK work then becomes much more bounded: add nRF52 support for a normal async UART byte stream and feed that into RMK’s existing serial split machinery.

## Recommended inter-half connector

Use a dedicated inter-half connector with enough conductors for full-duplex serial, power, detection, and future expansion.

Minimum useful signals:

| Signal | Purpose |
| --- | --- |
| GND | Shared reference |
| Wired power / VBUS / 5V | Powers peripheral half and LED rail in wired mode |
| UART TX central → peripheral RX | Wired split data |
| UART RX central ← peripheral TX | Wired split data |
| Cable detect | Lets firmware choose wired mode at boot |
| Spare GPIO | Future reset, boot, wake, interrupt, or debug signal |

That is a **minimum of 6 conductors**. Prefer **8+ conductors** if the connector allows it.

### Connector options

Good options:

| Connector | Notes |
| --- | --- |
| USB-C as dumb interconnect | Compact, reversible, many conductors, easy cables; must be clearly marked and protected because it is not real USB |
| JST-GH / JST-SH / Molex PicoBlade | Electrically safer, keyed/locking, less likely to be misused |
| RJ12 / RJ45 | Cheap cables, many conductors, robust; physically larger |
| Magnetic pogo / custom dock | Nice UX, more mechanical complexity |

Avoid TRRS unless compatibility with existing keyboard conventions matters. Since this is a from-scratch design, TRRS is not worth the limitations.

## Proposed inter-half pinout concept

Example 8-conductor inter-half cable:

| Pin | Signal | Notes |
| --: | --- | --- |
| 1 | GND | Ground reference |
| 2 | GND | Second ground for robustness |
| 3 | 5V wired power | Powers peripheral in wired mode |
| 4 | LED power or switched 5V  | Optional separate LED rail |
| 5 | UART TX A→B | Central TX to peripheral RX |
| 6 | UART RX A←B | Peripheral TX to central RX |
| 7 | Cable detect / mode sense | Pulled to known state when cable present |
| 8 | Spare GPIO | Future reset/wake/debug/mode line |

The exact pinout should be chosen alongside connector and power-path design.

If USB-C is used as the physical connector, do not pretend this is USB protocol. Treat it as a keyed multi-pin connector and add protection/marking accordingly.

## LED power design

Do not rely only on firmware to disable LEDs in portable mode.

Design the LED power rail so it is physically unavailable from battery, or at least hardware-gated off by default.

Recommended power domains:

| Rail | Source | Purpose |
| --- | --- | --- |
| MCU/matrix rail | Battery or USB | Keyboard logic |
| LED rail | Wired power only, or load-switched from wired power | Per-key LEDs |
| LED data | MCU GPIO through appropriate resistor/protection | LED control |

Key safety property:

> In portable mode, the LEDs should not be able to drain the battery even if firmware crashes, a GPIO floats, or the LED driver misbehaves.

Possible implementation:

1. LED rail is powered only from wired/inter-half power.
2. LED rail is controlled by a load switch or MOSFET.
3. The load switch defaults off.
4. Firmware only enables the LED rail when wired power is detected.
5. LED data line has protection to avoid phantom-powering LEDs when the LED rail is off.

Because this is only a 36-key board, the LED current budget is smaller than on a large keyboard, but still large enough to dominate battery life if accidentally enabled.

## Power architecture

Each half should be able to run from battery in portable mode.

In wired mode:

* The central half receives USB power from the host.
* The peripheral half receives wired power through the inter-half connector.
* LED power is available only in wired mode.
* The peripheral half should not need to draw LED current from its battery.

Power-path design must avoid unsafe backfeeding:

* USB/wired power should not backfeed into a battery incorrectly.
* Peripheral battery should not try to power the LED rail.
* A powered central half should not accidentally charge or feed the peripheral battery unless the design explicitly supports that.
* The keyboard should behave safely if one half has a battery and the other does not.

## Firmware strategy

### Phase 1: prove BLE mode

Build or adapt RMK firmware for:

* nRF52840 central.
* nRF52840 peripheral.
* BLE host connection.
* BLE split connection.
* LEDs disabled.

Success criteria:

* Both halves scan keys.
* Central reports to host over BLE.
* Reconnect behaviour is acceptable.
* Battery current is plausible.
* Peripheral half works independently from its own battery.

### Phase 2: prove USB host + BLE split

Build a mode where:

* Central talks to host over USB.
* Halves still communicate over BLE.
* LEDs remain disabled or test-only.

This is not the final home mode, but it validates the USB host path and RMK’s documented “USB host while BLE split” behaviour.

Success criteria:

* Central reports over USB.
* Peripheral half still contributes keys over BLE split.
* No obvious conflict between USB host output and BLE split.

### Phase 3: implement/prove nRF52840 full-duplex serial split

This is the key custom RMK work.

Goal:

* Central talks to host over USB.
* Central talks to peripheral over full-duplex UART.
* Peripheral sends key state over UART.
* LEDs can be enabled in wired mode.

Likely implementation work:

1. Add an nRF52/nRF52840 branch to RMK’s serial split initialisation macro.
2. Instantiate an Embassy nRF UARTE/BufferedUarte peripheral.
3. Bind the appropriate UARTE interrupt.
4. Allocate RX/TX buffers correctly.
5. Configure TX/RX pins from RMK config.
6. Ensure the resulting serial object satisfies RMK’s async read/write trait bounds.
7. Test both central and peripheral builds.

Expected difficulty:

| Goal | Rough effort |
| --- | ---: |
| Hack it until it compiles | 0.5–1 day |
| Get UART bytes moving between two nRF52840 boards | 0.5–1 day |
| Make RMK serial split work reliably | 2–5 days |
| Make it clean/upstreamable | 1–2 weeks |
| Add robust runtime mode switching | Later stretch goal |

### Phase 4: boot-time mode selection

Once BLE split and serial split both work separately, attempt a single firmware that chooses mode at boot.

Boot logic concept:

```text
if inter_half_cable_present && usb_or_wired_power_present {
    start USB host output
    start serial split
    enable LED power
} else {
    start BLE host output
    start BLE split
    keep LED rail disabled
}
```

Mode change can require reset/reboot. That is acceptable.

### Phase 5: optional hot switching

Hot switching is a stretch goal and should not drive the first hardware revision.

Potential challenges:

* Stopping BLE split cleanly.
* Starting serial split after boot.
* Reinitialising host output.
* Resynchronising split state.
* Avoiding stuck keys during transition.
* Handling cable insertion/removal.
* Managing LED rail power safely.
* Preserving BLE pairing and reconnect behaviour.

## Hardware design principles

### Preserve options

Because the software path may evolve, the PCB should preserve flexibility:

* Route full-duplex UART between halves.
* Add cable detect.
* Add wired power detect.
* Add LED power enable/sense.
* Expose SWD on both halves.
* Expose reset/boot access on both halves.
* Leave spare GPIOs.
* Keep the matrix simple.
* Avoid sharing critical debug or UART pins with awkward hardware.

### Do not over-optimise the matrix

With only 18 keys per half, GPIO pressure should be manageable.

Prefer a simple matrix over clever pin saving. For example:

* A straightforward 3×6 matrix per half is easy to reason about.
* It leaves enough pins for UART, LEDs, battery sense, cable detect, and debug.
* It reduces firmware bring-up complexity.

### Avoid fragile interconnect assumptions

Do not build the first revision around:

* Single-wire serial.
* TRRS hot-plug behaviour.
* USB protocol between halves.
* USB-C Power Delivery.
* Automatic hot switching.
* Peripheral half being powered through accidental paths.
* Firmware-only LED disable.

## Risk register

| Risk | Severity | Mitigation |
| --- | ---: | --- |
| RMK stock serial split does not support nRF52840 | High | Plan to implement nRF52 full-duplex UART serial split |
| nRF52 UARTE integration takes longer than expected | Medium | Prototype on dev boards before PCB |
| Runtime mode switching is too hard | Medium | Accept boot-time mode selection or separate firmware builds |
| Hot switching is too hard | Low | Treat as stretch goal |
| LED rail drains battery | High | Hardware-gate LED power; wired-power-only LED rail |
| USB-C inter-half connector is mistaken for USB | Medium | Use keyed connector or add protection/clear labelling |
| Peripheral power path backfeeds battery/USB | High | Use proper power-path/load-switch/ideal-diode design |
| BLE performance or reconnect behaviour is poor | Medium | Prototype early with real batteries/enclosure assumptions |
| Too few GPIOs | Low/medium | 36-key layout gives margin; reserve pins early |
| Debug access awkward after assembly | Medium | Add accessible SWD pads, reset, boot, test pads |

## Early prototype checklist

Before committing to a full custom PCB, build a proof of concept with dev boards.

### Prototype A: BLE split

Goal:

* Two nRF52840 boards.
* RMK BLE split.
* Host over BLE.
* No LEDs.

Success criteria:

* Both halves scan keys.
* Central reports to host over BLE.
* Battery behaviour is plausible.

### Prototype B: USB host + BLE split

Goal:

* Same BLE split setup.
* Central plugged into USB host.

Success criteria:

* Central reports to host over USB.
* Inter-half remains BLE.
* Confirms the USB host path on the central half.

### Prototype C: raw nRF52840 UART

Goal:

* Two nRF52840 boards.
* Full-duplex UART between them.
* Independent of full RMK split at first if needed.

Success criteria:

* Bytes move reliably both directions.
* Chosen TX/RX pins work.
* Embassy UARTE setup is understood.
* Buffer and interrupt requirements are clear.

### Prototype D: RMK USB host + nRF52840 serial split

Goal:

* Custom RMK changes.
* Central reports to host over USB.
* Halves communicate over full-duplex UART.

Success criteria:

* Both halves scan keys.
* Split state is reliable.
* No panic from missing serial implementation.
* Firmware structure is clean enough to keep iterating.

### Prototype E: LED power gating

Goal:

* Add representative per-key LED chain or LED load.
* Power LEDs only from wired power.

Success criteria:

* LEDs work in wired mode.
* LEDs remain physically unpowered in battery mode.
* MCU remains stable when LED rail is off.
* LED data line does not phantom-power LED rail.

### Prototype F: boot-time mode selection

Goal:

* Detect wired cable/power at boot.
* Choose wired or wireless mode.

Success criteria:

* Boot with cable: USB host + serial split + LEDs available.
* Boot without cable: BLE host + BLE split + LEDs disabled.
* Reset is acceptable for mode changes.

## Recommended first concrete decision

Proceed with an **nRF52840-based 36-key split design**, but assume that wired serial split support must be implemented or adapted in RMK.

The most important technical proof-of-concept is:

> Can two nRF52840 boards run RMK with USB-to-host and full-duplex UART serial between halves?

If yes, the hardware platform is likely safe.

If no, decide whether to:

1. Continue implementing nRF52 serial split support in RMK.
2. Switch to RP2040/Pico W for stock RMK serial split support.
3. Drop fully wired inter-half mode and accept USB-to-host plus BLE-between-halves.

## Current recommendation

Use:

* **nRF52840** on both halves.
* **36-key layout**, 18 keys per half.
* **BLE split** for portable mode.
* **Full-duplex UART serial split** for wired mode.
* **USB host connection on central half**.
* **Dedicated inter-half connector** carrying power, ground, UART TX/RX, cable detect, and spare GPIO.
* **Hardware-gated LED power rail** unavailable in portable mode.
* **Boot-time mode selection** as the realistic custom firmware target.
* **Hot switching** only as a later stretch goal.

This design keeps both desired modes open without relying on single-wire TRRS assumptions or pretending that stock RMK already supports nRF52840 serial split.

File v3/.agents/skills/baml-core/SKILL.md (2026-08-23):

---
name: baml-core
description: Minimal BAML skill. BAML is a statically-typed, expression-oriented language with first-class LLM functions — TypeScript-like, snake_case methods, etc. Useful for building ai workflows, agents, evals.
---

# baml

BAML is a statically-typed, expression-oriented *language* — TypeScript with `snake_case` methods, `name: type,` fields, enums, interfaces, generics, closures, optional chaining, backtick strings with `${...}` interpolation, `.to_string()` on any value, a real stdlib. And a declarative *DSL* for LLM calls (`function … { client: prompt: }`, `test`) that desugars into it, so a model's structured output is just a typed return value.

**The CLI is the documentation. Discover via `baml describe`:**

```bash
brew install baml                # CLI binary: `baml`

baml init                        # new project (baml.toml + baml_src/)
baml help <command>              # CLI options and examples
baml describe baml.json          # ← THE reference for any module/type/method/signature/keyword
baml describe Array --budget 120 #   (Array, String, Map, assert, match, patterns, spawn, python, ...)
                                 #   ends with "… N more lines"? re-run with `--budget <N>`
baml check                       # compile-check the project
baml run -e 'expr'               # eval an expression — fast feedback + syntax check
baml test --list && baml test    # run every test/testset block
baml fmt baml_src/main.baml      # canonicalize the project's formatting
```

`baml describe <name>` prints the **full source body** of stdlib functions — the fastest way to verify behavior, and the only path for embedded builtins like `assert` (no on-disk file). Pure functions need no test/client — check them with `baml run -e 'add(2, 3)'`.

Don’t describe APIs already demonstrated below unless you run into some errors. You can start based off the examples and use it if you run into more errors or you want actual stdlib details.

Mostly it behaves like JavaScript/TypeScript, with very similar syntax — but BAML is more sound/strict.

## Best practices and info

- **LLM function = typed return.** The RETURN TYPE *is* the schema the model must produce (`class`, `enum`, literal union, `string[]`, `T?`). Structured output is just a typed value — hand it to ordinary code.
- **Prompts are backtick strings with `${...}` interpolation.** Write `prompt:` ``… ${arg} …``, and **always inject `${ctx.output_format}`** for a structured return. Escape with `\`` / `\${`; nest with extra backticks.
- **Clients are values, not config blocks.** `client Fast = openai.OpenAiClient.new(model = "…", api_key_env = "OPENAI_API_KEY");` — the old `client<llm> Name { provider: …, options: {…} }` block is **removed**. Anything implementing `ai.Client` works (`openai.OpenAiClient`, `anthropic.AnthropicClient`, …; note their `new` params differ — OpenAI takes `api_key_env`/`base_url_env`, Anthropic takes `max_tokens`). **Use `api_key_env = "NAME"`, not `api_key = env.NAME`** — `env.*` is read eagerly at engine init, so one unset var fails the entire project with an opaque `InitFailed(… BamlEnvGet …)` before any test runs; `api_key_env` resolves lazily at call time. Compose reliability by **wrapping**: `ai.clients.Retry.new(inner = c, max_attempts = 3)` and `ai.clients.RoundRobin.new(members = […])` have `.new`, but `ai.clients.Fallback { members: […] }` does **not** — construct it as a class literal. Then `client: Fast` in the function, or the shorthand `client: "openai/gpt-4o-mini"`. `baml describe ai.clients`.
- **Shape the schema with field attributes.** `@description("…")` adds a `///` hint the model sees in `${ctx.output_format}`; `@alias("name")` renames the emitted JSON key. Chain: `tags: string[] @alias("labels") @description("…")`.
- **Test the pure code, not the model.** Unit-test orchestration/post-processing on literal data with `assert.`*. Calling an LLM function in a `test` makes a real request — not an offline test. (`f$parse`/`f$render_prompt`/`f$build_request` exist for debugging.)
- **Build strings with interpolation, not coercion.** ``score=${n}`` stringifies any value (implicit `.to_string()`); call `.to_string()` for the string alone. `+` needs both sides already strings (`"n=" + 5` won't compile).
- `**catch` for some, `catch_all` for all.** `expr catch (e) { baml.errors.ParseError => fallback }` handles a *specific* error; `expr catch_all (e) { _ => fallback }` is *exhaustive* — for a workflow top / entrypoint. Errors propagate implicitly; callers needn't re-declare. **Raise** with `throw baml.errors.InvalidArgument { message: "…" }` (error types are the builtin `baml.errors.*` classes — `InvalidArgument`/`ParseError`/`Io`/`Timeout`/…; `baml describe baml.errors`); annotate a fallible signature with `-> T throws ErrType`. Prefer a typed result **union** (`type R = Ok | Err`) over throwing for ordinary control flow.
- **Interfaces = shared behavior + dynamic dispatch.** `interface I { function m(self) -> T throws never }` (methods may have default bodies); a class opts in via `implements I { … }`; a value typed `I` (or `I[]`) dispatches to the implementor at runtime. Interface methods **must** declare an explicit `throws` clause — `throws never` when the method can't fail, `throws SomeError` when it can (omitting it is an error: *interface method `m` must declare an explicit `throws` clause*). The `implements` block does **not** repeat the clause.
- **Pattern matching.** `match (v) { … }` over values/types; arms are `pattern => expr` — literals, `let x: T` (bind + narrow), class destructure `T { f: let y }`, or-patterns `A | B`, guards `… if cond`, `_`; must be exhaustive. Also `v is T` → bool (narrows) and `if let x: T = v { … } else { … }`. `baml describe patterns`.
- **Concurrency = green threads.** `spawn { … }` returns a `Future`; `await` collects it. Combine many with `baml.future.all` / `all_complete` / `race` / `any` (JS `Promise.*`). Configure a spawn with a `with` clause: `spawn with baml.spawn.options(group = g, cancel = tok, detach = true) { … }` — `baml.spawn.TaskGroup.new(n)` caps concurrency (excess spawns queue FIFO), a `baml.spawn.CancelToken` cancels cooperatively. `baml describe spawn` / `baml describe baml.future`.
- **Resource safety — `defer`, `cleanup`, `catch (e, ctx)`.** `defer { … }` runs a block at scope exit, LIFO, on *every* path (return / throw / fall-through) — like Go. A class method named `function cleanup(self) -> void` is a **finalizer**: it runs at most once per instance whether you call it, `defer` it, or the GC reclaims it. `catch (e, ctx)` binds an **`ErrorContext`** alongside the error — an error thrown while handling another chains onto it, so `ctx.root_cause()` / `ctx.cause` walk back to the original failure and `ctx.to_string()` renders the whole chain (Python `__context__`-style). `while let PATTERN = expr { … }` loops until the pattern fails (e.g. draining a `T?`-returning `.pop()`).
- **Call BAML from Python / TS.** Declare a `[generator.<name>]` in `baml.toml`, run `baml generate`, then import the typed `baml_sdk`. Install + usage: `baml describe python` / `baml describe typescript` / `baml describe baml_sdk`.
- **Safe access over indexing.** Subscript panics on a missing index/key; use `.at(i)`/`.get(k)` (→ `T?`), reach through with `?.`, default with `??` (parenthesize: `(m.get(k) ?? 0) + 1`).
- **Stdlib methods are snake_case, called on a value.** Some return new, some mutate in place, a few do both (`sort_by_key` sorts the receiver *and* returns it) — to read the docs, `baml describe <word/type/identifier/keyword/etc>`.
- **Class fields `name: type,`; construct `Type { field: val }`.** Methods take a bare `self`; factories are free functions. **Fields are mutable** (like TS): `obj.field = v` and `obj.field += n` work, and a `self` method can mutate in place — a side-effect method returns `void`. **Classes are reference types**: `find`/`at(i)`/subscript return a *live alias*, not a copy, so mutating the result mutates that element inside the array (`xs.find(p)?.n += 1` updates `xs`), and a class passed to a function can be mutated by the callee. **Avoid struct-update spread for now** — reconstruct or mutate instead. `User { ...u, tier: Tier.Free }` compiles and runs, but `baml fmt` **rejects** it (`found SPREAD_ELEMENT`), so a file using it can't be formatted; prefer the explicit form until that lands. **Empty classes are legal** (`class Marker {}`) — handy as union variants. **Enums are plain variants — no methods, no associated data** (`E.A.foo()` won't compile); put behavior in free functions that `match`. `enum E { A, B }`, access `E.A`.
- **Blocks are expressions** — last expression is the value (no `;`); `return x;` for early exit. A side-effect-only function's return type is `-> null` (canonical — `baml describe void`; `-> void` also works); its block's unit *value* is just bare `null` (writing `-> null` in *value* position is a parse error). `for (let x in xs)` iterates VALUES; `while (cond) { … }` loops. Closures `(x) -> { ... }` infer param/return from context (annotate `(x: T) -> R` only when ambiguous; the `->` is required). `.map`/`.filter` return arrays directly (no `.collect()`). Empty map needs a type: `let m: map<string, int> = {};`.
- **No ternary — `if/else` is the expression.** There's no `cond ? a : b`; `if (cond) { a } else { b }` *is* an expression that returns a value, so assign it directly: `let label = if (x > 3) { "big" } else { "small" };`. Each branch is a block whose last expression is its value (no `return`). Chain with `else if`, and pair with `if let PATTERN = expr { … } else { … }` for bind-and-narrow.
- **Arrays have a JS-like method set** — `map`/`filter`/`filter_map`/`reduce`/`find`/`some`/`every`/`flat_map`/`slice`/`concat`/`join`/`includes`/length(), plus in-place `push`/`pop`/`shift`/`unshift`/`sort_by`/`sort_by_key`. Most take closures that can `throws`. `baml describe Array` gives more info.
- Local let bindings are reassignable (x = x + 1) — no mut keyword (it's TS let, not Rust); there's no const either.
- **Args: defaults with `=`, keyword calls with `=` (never `:`).** Declare a default in the signature: `function f(a: int, b: int = 10)`; call `f(1)` or `f(1, b = 2)`. A **defaulted param must be passed by name** — `f(1, 2)` is an error (`defaulted parameter 'b' must be passed by name`). Any param (even required) may be passed by name (`f(a = 1, b = 2)`), and you can skip a middle default to set a later one (`f(1, c = 9)`). Keyword syntax is `name = value`; `name: value` won't parse (`:` is for types/fields). **`T?` does NOT make an argument optional** — unlike TS `b?: T`, a `b: T?` param is still *required* (you must pass `null`, else `expected N argument(s), got …`); add `= null` to make it omittable. Built-ins follow this: `baml.http.fetch(url, timeout = baml.time.Duration.from_seconds(10))`.
- **Where it diverges from TS (the silent traps):** arithmetic is *type-driven*, not TS-style. `int / int` is **truncating integer division** (`285 / 100 == 2`, NOT `2.85`) and `%` is the remainder (`285 % 100 == 85`); this compiles fine and just gives a quietly-wrong number, so it's the highest-value gotcha. Mix in a float to get float division (`285 / 100.0 == 2.85`, `285.0 / 100 == 2.85`); any mixed `int`/`float` op promotes to `float` (`5 + 2.0 == 7.0`). There is **no `.to_float()`** — convert an int with `n * 1.0` (or divide by a float). An `int` result does **not** auto-coerce to `float` on assignment (`let x: float = 285 / 100` is a compile error). `+` is **numeric-only**: string concat needs both sides already `string` (`"n=" + 5` won't compile — use `${...}` interpolation). Comparisons (`==`, `<`, …, structural `==`) and `&&`/`||`/`!` are TS-like.
- **Tests:** lone `test "name" { ... }` (no wrapper); `testset` only GROUPS. Asserts (only 5): `assert.equal`/`approx_equal`/`is_true`/`not_null`/`contains`. `assert.equal` compares **structurally** (deep, across classes/arrays/maps) — and so does plain `==`, which is the bool form. `assert.equal` is *exact* on floats; use `assert.approx_equal(actual, expected, eps)` for computed ones. Last assert: no trailing `;`. Run one: `baml test -i "Testset::TestName"` (`-x` to exclude) — the selector keys on `testset::test`, so a top-level `test` with no testset is `-i "::TestName"`; `baml test --list` prints valid selectors.
- **Namespaces =** `ns_*` **directories, no imports.** A folder `ns_<name>/` under `baml_src/` puts its files in namespace `<name>`; files in `baml_src/` itself are the `root` namespace (nesting stacks — `ns_a/ns_b/` → `root.a.b`; non`ns_` folders don't namespace). Same namespace = same scope: files share definitions with no import. To reach *another* namespace, use the **absolute** path `root.<ns>.<name>` `root.llm.Response`) — a bare `Response` from outside is rejected `did you mean root.Response?`). Run a target by its namespace-relative path `baml run agent.main`), but `baml run -e` evaluates in the root scope, so reach in with the absolute form: `baml run -e 'root.agent.main()'`. It's more idiomatic to keep namespaces as flat as possible, like Go packages.
- Run `baml fmt` when you're done with a feature.
- BAML functions/methods/types etc are accessible from other languages (python, typescript). Run `baml describe baml_sdk` for setup instructions. You might want to see if the current dir is near a python or TS project to setup the wiring for the user. The baml.toml toolchain version must match the installed python/ts baml package. Keep AI-related things and workflow logic in BAML as much as possible.
- BAML has `log.info(..)` or `log.debug(..)`
- `baml pack` can create a binary.
- Use backtics instead of \#" "# like baml used to have.

For anything not shown (signatures, niche stdlib, advanced features), run `**baml describe <name>`** — the CLI is the docs; never guess the stdlib.

## Example 1 — LLM DSL + glue (schema, attributes, client, backtick prompt, post-processing)

```baml
// The return type IS the schema; @description/@alias shape what the model sees.
enum Priority { High, Low }

class LineItem {
    name: string,
    amount: float,
    priority: Priority,
}

class Invoice {
    vendor: string @alias("seller"),
    status: "draft" | "final" @description("invoice state"),
    items: LineItem[],
    note: string?,
}

// Clients are ordinary VALUES implementing `ai.Client` (no `client<llm> { }` config block).
// Prefer `api_key_env = "NAME"` (resolved lazily) over `api_key = env.NAME` — the latter is
// read at engine init, so an unset var fails the WHOLE project, even offline tests.
client Fast = openai.OpenAiClient.new(model = "gpt-4o-mini", api_key_env = "OPENAI_API_KEY");
// Compose reliability by WRAPPING a client. `Retry`/`RoundRobin` have `.new(...)`;
// `Fallback` has no `.new`, so construct it as a class literal.
client Reliable = ai.clients.Retry.new(inner = Fast, max_attempts = 3);
client Safe = ai.clients.Fallback { members: [Reliable, anthropic.AnthropicClient.new(model = "claude-sonnet-5")] };

function Extract(raw: string) -> Invoice {
    client: Reliable                              // or shorthand: "openai/gpt-4o-mini"
    prompt: `Extract the invoice. ${ctx.output_format}\n${raw}`
}

// Structured output is just a typed value — hand it to ordinary code.
// Closure params/return infer from context; only the -> is required.
// `min_amount` has a default — omit it, or pass it BY NAME (`min_amount = …`).
function high_total(inv: Invoice, min_amount: float = 0.0) -> float {
    inv.items
        .filter((i) -> { i.priority == Priority.High && i.amount >= min_amount })
        .reduce((a, i) -> { a + i.amount }, 0.0)
}

test "post-process a literal Invoice — no model call" {
    let inv = Invoice {
        vendor: "Acme", status: "final", note: null,
        items: [LineItem { name: "srv", amount: 900.0, priority: Priority.High },
                LineItem { name: "mug", amount: 12.0, priority: Priority.Low }],
    };
    assert.equal(high_total(inv), 900.0);                        // default min_amount = 0.0
    assert.equal(high_total(inv, min_amount = 1000.0), 0.0)      // keyword arg
}
```

## Example 2 — the language (methods, interpolation, closures, maps, json, errors). Mutations work like Typescript

```baml
// BAML is a real language — no LLM here.
enum Tier { Free, Pro }

class User {
    name: string,
    tier: Tier,
    score: int,
    // method (bare self) + ${} interpolation (implicit .to_string() on the int)
    function label(self) -> string { `${self.name.to_upper_case()}:${self.score}` }
    // fields are MUTABLE like TS: assign / += on self in place; a side-effect method returns void
    function celebrate(self) -> void { self.score += 100 }
}

function make_user(name: string, score: int) -> User { User { name: name, tier: Tier.Pro, score: score } }

// inferred closures; sort_by_key; optional chaining + ?? over a possibly-null .at
function top_label(us: User[]) -> string {
    us.sort_by_key((u) -> { 0 - u.score }).at(0)?.label() ?? "none"
}

// map<string,int> via for-let-in; .get ?? default; explicit .to_string()
function tier_counts(us: User[]) -> map<string, int> {
    let counts: map<string, int> = {};
    for (let u in us) { let _ = counts.set(u.tier.to_string(), (counts.get(u.tier.to_string()) ?? 0) + 1); }
    counts
}

function roundtrip(u: User) -> User { baml.json.from_string<User>(baml.json.to_string(u)) }

// `catch` with a typed arm handles ONE specific error
function safe_parse(s: string) -> int { baml.Int.parse(s) catch (e) { baml.errors.ParseError => -1 } }

test "lang" {
    let us = [make_user("ada", 90), make_user("bo", 30)];
    log.info(us);
    assert.equal(top_label(us), "ADA:90");
    assert.equal((tier_counts(us).get("Pro") ?? 0), 2);
    let kit = make_user("kit", 5);
    kit.celebrate();            // mutate in place
    kit.tier = Tier.Free;       // direct field assignment
    assert.equal(kit.score, 105);
    assert.equal(roundtrip(make_user("zoe", 7)).name, "zoe");
    assert.equal(safe_parse("42"), 42);
    assert.equal(safe_parse("x"), -1)
}
```

## Example 3 — interfaces (shared behavior, default method, dynamic dispatch)

```baml
// Interface methods MUST declare an explicit throws clause: `throws never` if the
// method can't fail, `throws SomeError` if it can. Implementors don't repeat it.
interface Animal {
    function sound(self) -> string throws never
    function describe(self) -> string throws never { `${self.sound()}!` } // default method
}

class Dog {
    name: string,
    implements Animal { function sound(self) -> string { "woof" } }
}

class Cat {
    indoor: bool,
    implements Animal {
        function sound(self) -> string { "meow" }
        function describe(self) -> string { `quiet ${self.sound()}` } // override
    }
}

// an Animal[] holds any implementor; calls dispatch dynamically
function chorus(animals: Animal[]) -> string {
    animals.map((a) -> { a.describe() }).join(" ")
}

test "interfaces" {
    let animals: Animal[] = [Dog { name: "Rex" }, Cat { indoor: true }];
    assert.equal(chorus(animals), "woof! quiet meow")
}
```

## Example 4 — pattern matching (`match` over values + types, `is`, `if let`)

```baml
class Circle { r: int }
class Rect { w: int, h: int }
type Shape = Circle | Rect

function area(s: Shape) -> int {
    match (s) {
        Circle { r: 0 } => 0,                           // literal field, no binding
        let c: Circle => 3 * c.r * c.r,                 // typed binding (matches + narrows)
        Rect { w: let w, h: let h } if w == h => w * w, // destructure + guard
        _ => 0,                                         // wildcard
    }
}

function classify(n: int) -> string {
    match (n) {
        0 => "zero",
        1 | 2 | 3 => "small",     // or-pattern
        let x if x < 0 => "neg",  // binding + guard
        _ => "big",
    }
}

// `is` -> bool (and narrows); `if let PATTERN = expr { } else { }`
function label(s: Shape) -> string {
    if (s is Circle) {
        "circle"
    } else if let r: Rect = s {
        `rect ${r.w}x${r.h}`
    } else {
        "?"
    }
}

test "patterns" {
    assert.equal(area(Circle { r: 2 }), 12);
    assert.equal(area(Rect { w: 3, h: 3 }), 9);
    assert.equal(classify(2), "small");
    assert.equal(classify(-5), "neg");
    assert.equal(label(Circle { r: 1 }), "circle");
    assert.equal(label(Rect { w: 2, h: 4 }), "rect 2x4")
}
```

## Example 5 — resource safety + structured concurrency (defer, cleanup, ErrorContext, spawn options, futures, while-let)

```baml
class DbConn {
    log: string[],
    // `cleanup` is a magic method (recognized by name): runs at most once per
    // instance — whether called explicitly, deferred, or reclaimed by the GC.
    function cleanup(self) -> void { self.log.push("closed") }
}

function use_conn() -> string[] {
    let c = DbConn { log: [] };
    {
        defer { c.cleanup() }              // deferred blocks run LIFO at scope exit,
        defer { c.log.push("commit") }     // on every path (return / throw / fall-through)
        c.log.push("query")
    }
    c.log                                  // ["query", "commit", "closed"]
}

function fail_a() -> string { throw baml.errors.Io { message: "disk full" } }
function fail_b() -> string { throw baml.errors.Timeout { message: "retry timed out" } }

// `catch (e, ctx)` binds the error AND its ErrorContext; throwing while handling
// chains the new error onto the one being handled, so root_cause() walks to the origin.
function root_cause_demo() -> string {
    fail_a() catch (e, ctx) {
        _ => fail_b() catch (e2, ctx2) {
            _ => match (ctx2.root_cause().error) {      // ctx.to_string() renders the full chain
                let io: baml.errors.Io => io.message,   // "disk full" — the original cause
                _ => "unknown",
            }
        }
    }
}

// spawn returns a Future; baml.future.all/all_complete/race/any combine many (JS Promise.*).
function concurrent_squares(xs: int[]) -> int {
    let futures = xs.map((x) -> { spawn { x * x } });   // all run concurrently
    let squares = await baml.future.all(futures);
    squares.reduce((a, b) -> { a + b }, 0)
}

// Configure a spawn with `with baml.spawn.options(...)`: a TaskGroup caps concurrency
// (excess spawns queue), a CancelToken cancels cooperatively, detach reparents the task.
function rate_limited() -> int {
    let g = baml.spawn.TaskGroup.new(2);
    let a = spawn with baml.spawn.options(group = g) { 1 };
    let b = spawn with baml.spawn.options(group = g) { 2 };
    (await a) + (await b)
}

// while-let drains an optional-returning source; the loop exits when the pattern fails.
function drain(stack: string[]) -> string {
    let out = "";
    while let item: string = stack.pop() { out = out + item; }
    out
}

test "resources + concurrency" {
    assert.equal(use_conn(), ["query", "commit", "closed"]);
    assert.equal(root_cause_demo(), "disk full");
    assert.equal(concurrent_squares([1, 2, 3]), 14);
    assert.equal(rate_limited(), 3);
    assert.equal(drain(["a", "b", "c"]), "cba")
}
```

## Concurrency — green threads (parallelize LLM / HTTP calls)

`spawn { … }` launches a background task; `await` collects it; `baml.future.all(list)` awaits many in order. Run `baml describe spawn` for the details.

```baml
function fetch_all(urls: string[]) -> string[] {
    // each request runs concurrently; await all results in order
    await baml.future.all(urls.map((u) -> { spawn { baml.http.fetch(u).text() } }))
}
```

**Workflow: sketch → `baml run -e` / `baml check` constantly → `baml describe` anything unfamiliar → `baml test`.**

Also just start writing some code. This is plenty of information already. Pretend you're writing some typescript but with this new syntax etc.

## BAML workflow visualizer annotations
Use '//#' to add comments that will show up in the BAML visualizer. Useful for annotating branches, general flow of the program. When you write baml code you should add some of these in general flow of the program. No need to annotate _everything_.
e.g.
```baml
function hello() -> void {
    //# Start loading data
    ...
    //# Iterate over things...
    ...
}

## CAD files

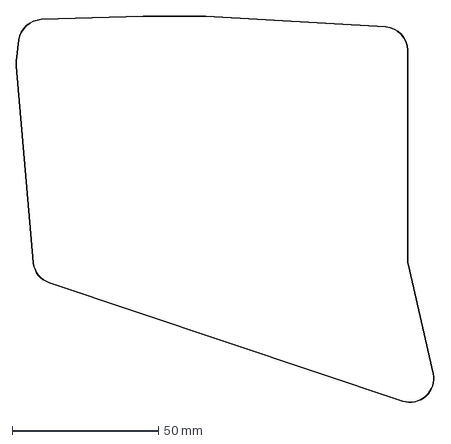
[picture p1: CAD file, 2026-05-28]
output_v2/outlines/board.dxf
143.2 x 132.4 mm

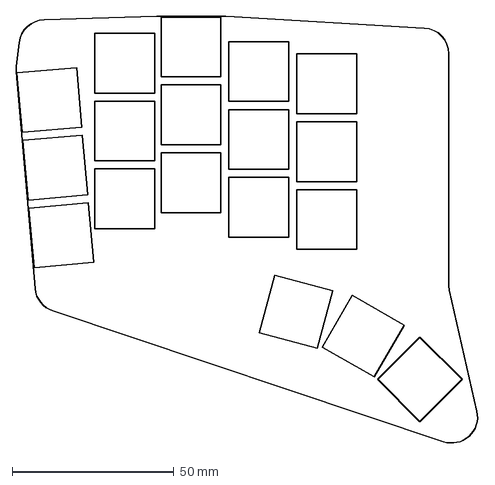
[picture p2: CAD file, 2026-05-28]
output_v2/outlines/combo.dxf
143.2 x 132.4 mm

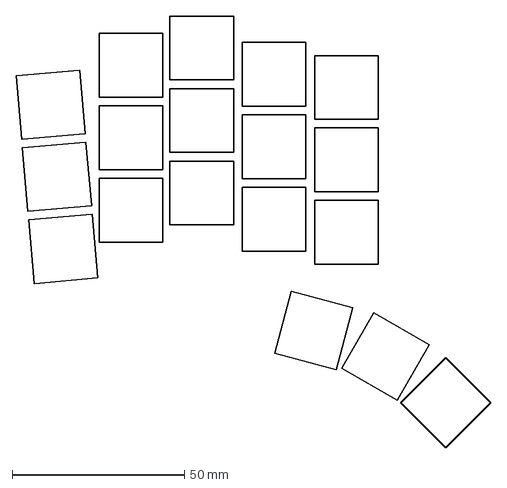
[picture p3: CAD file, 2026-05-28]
output_v2/outlines/keys.dxf
137.7 x 125.2 mm

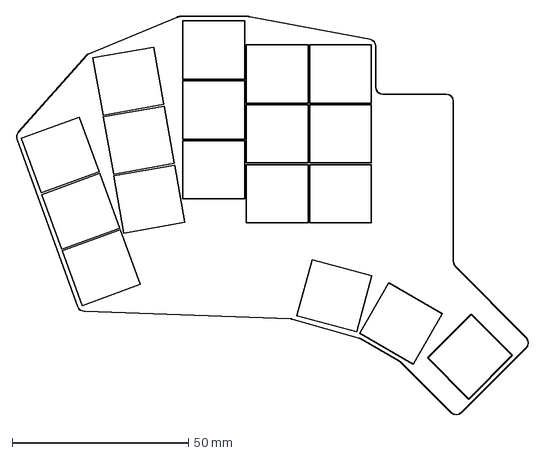
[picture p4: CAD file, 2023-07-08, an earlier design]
output/outlines/combo.dxf
145.4 x 113.2 mm

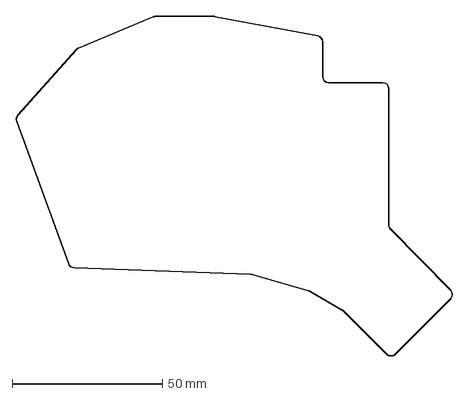
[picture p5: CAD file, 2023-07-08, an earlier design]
output/outlines/board.dxf
145.4 x 113.2 mm

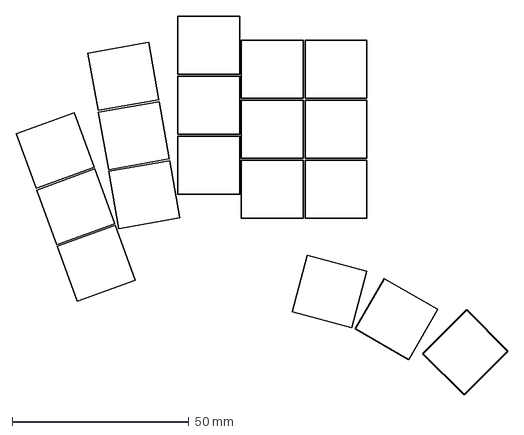
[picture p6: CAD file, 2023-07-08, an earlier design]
output/outlines/keys.dxf
139.3 x 107.2 mm

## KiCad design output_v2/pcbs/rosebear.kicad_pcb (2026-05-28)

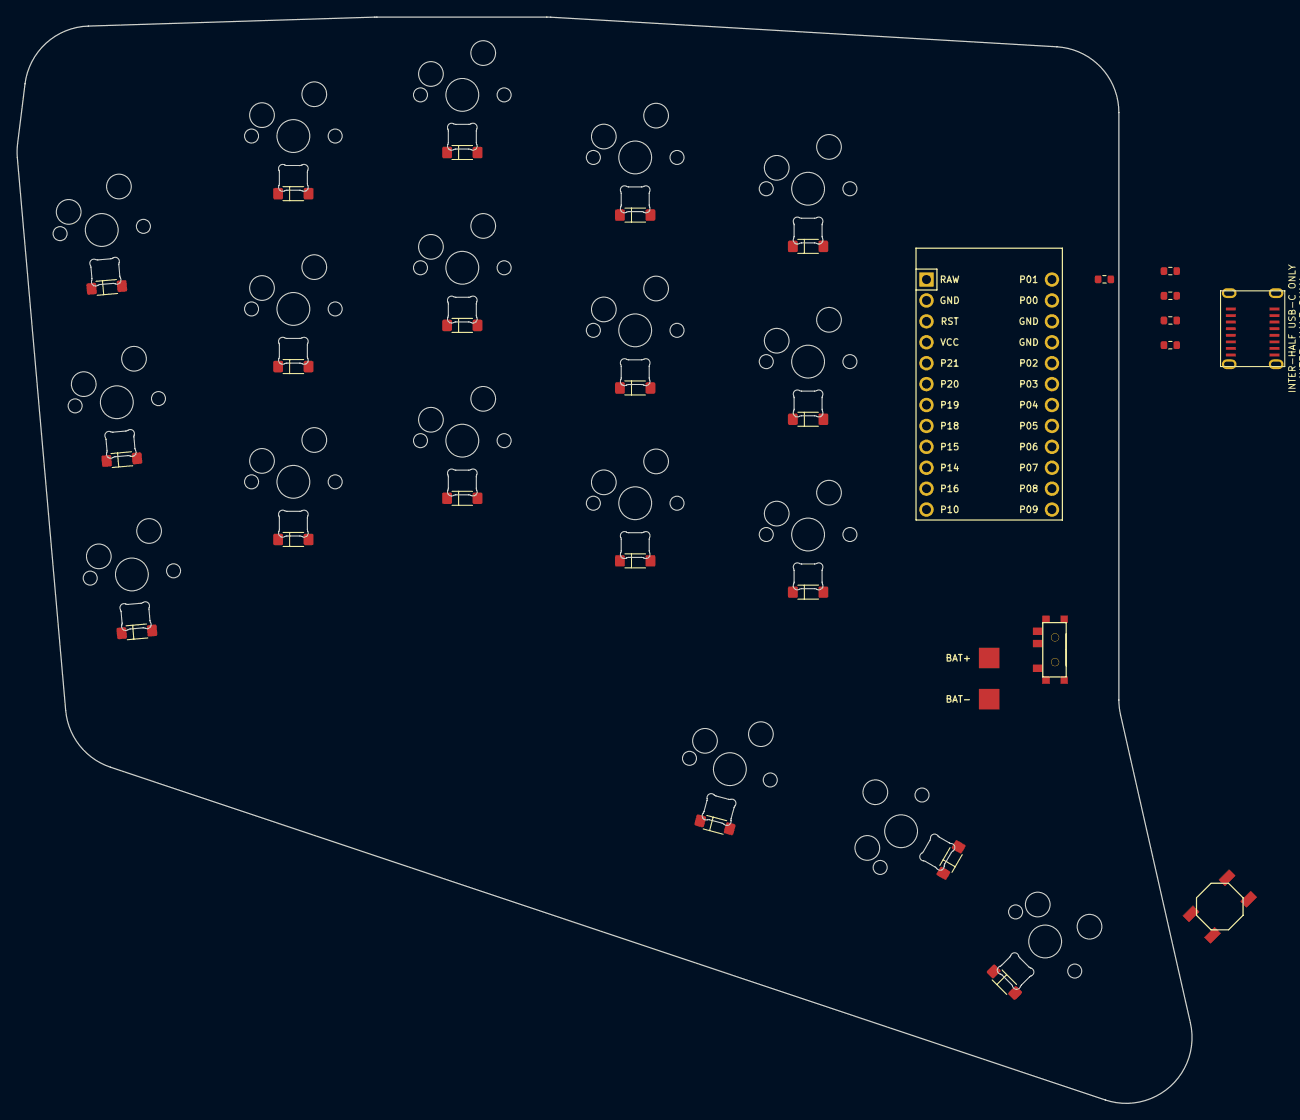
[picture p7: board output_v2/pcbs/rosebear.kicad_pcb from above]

Board: 2 copper layers, 142.7 x 131.9 mm, 65 parts (0 on the bottom side), 60 nets, no tracks yet.

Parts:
B1: SW_TACT_ALPS_SKQGABE010
D1, D2, D3, D4, D5, D6, D7, D8, D9, D10, D11, D12, D13, D14, D15, D16, D17, D18: SOD-123
J1: INTER-HALF USB-C ONLY; USB-C_inter_half_placeholder
LED1, LED2, LED3, LED4, LED5, LED6, LED7, LED8, LED9, LED10, LED11, LED12, LED13, LED14, LED15, LED16, LED17, LED18: SK6812MINI-E; SK6812MINI-E_MX-reverse
MCU1: ProMicro
PAD1, PAD2: SMDPad
R1, R2, R3, R4, R5: R_0603; R_0603_1608Metric
S1, S2, S3, S4, S5, S6, S7, S8, S9, S10, S11, S12, S13, S14, S15, S16, S17, S18: MX
T1: SPDT_C128955

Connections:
Bplus: PAD1.1, T1.1
COL0: MCU1.8, S1.1, S2.1, S3.1
COL1: MCU1.9, S4.1, S5.1, S6.1
COL2: MCU1.10, S7.1, S8.1, S9.1
COL3: MCU1.11, S10.1, S11.1, S12.1
COL4: MCU1.12, S13.1, S14.1, S15.1
COL5: MCU1.13, S16.1, S17.1, S18.1
GND: B1.1, J1.A1, J1.A12, J1.B1, J1.B12, J1.S1, J1.S2, J1.S3, J1.S4, LED1.3, LED2.3, LED3.3, LED4.3, LED5.3, LED6.3, LED7.3, LED8.3, LED9.3, LED10.3, LED11.3, LED12.3, LED13.3, LED14.3, LED15.3, LED16.3, LED17.3, LED18.3, MCU1.2, MCU1.15, MCU1.16, PAD2.1
IH_DETECT_CONN: J1.A5, J1.B5, R4.2
IH_DETECT_MCU: MCU1.19, R4.1
IH_RX_CONN: J1.A7, J1.B7, R3.2
IH_RX_MCU: MCU1.18, R3.1
IH_SPARE_CONN: J1.A8, J1.B8, R5.2
IH_SPARE_MCU: MCU1.20, R5.1
IH_TX_CONN: J1.A6, J1.B6, R2.2
IH_TX_MCU: MCU1.17, R2.1
LED_01: LED3.2, LED6.4
LED_02: LED6.2, LED9.4
LED_03: LED9.2, LED12.4
LED_04: LED12.2, LED15.4
LED_05: LED14.4, LED15.2
LED_06: LED11.4, LED14.2
LED_07: LED8.4, LED11.2
LED_08: LED5.4, LED8.2
LED_09: LED2.4, LED5.2
LED_10: LED1.4, LED2.2
LED_11: LED1.2, LED4.4
LED_12: LED4.2, LED7.4
LED_13: LED7.2, LED10.4
LED_14: LED10.2, LED13.4
LED_15: LED13.2, LED16.4
LED_16: LED16.2, LED17.4
LED_17: LED17.2, LED18.4
LED_DATA_MCU: MCU1.14, R1.1
LED_DIN: LED3.4, R1.2
LED_VDD: LED1.1, LED2.1, LED3.1, LED4.1, LED5.1, LED6.1, LED7.1, LED8.1, LED9.1, LED10.1, LED11.1, LED12.1, LED13.1, LED14.1, LED15.1, LED16.1, LED17.1, LED18.1
RAW: MCU1.1, T1.2
ROW0: D3.1, D6.1, D9.1, D12.1, D15.1, D18.1, MCU1.5
ROW1: D2.1, D5.1, D8.1, D11.1, D14.1, D17.1, MCU1.6
ROW2: D1.1, D4.1, D7.1, D10.1, D13.1, D16.1, MCU1.7
RST: B1.2, MCU1.3
WIRED_5V: J1.A4, J1.A9, J1.B4, J1.B9
matrix_index_bottom_SW: D10.2, S10.2
matrix_index_home_SW: D11.2, S11.2
matrix_index_top_SW: D12.2, S12.2
matrix_inner_bottom_SW: D13.2, S13.2
matrix_inner_home_SW: D14.2, S14.2
matrix_inner_top_SW: D15.2, S15.2
matrix_middle_bottom_SW: D7.2, S7.2
matrix_middle_home_SW: D8.2, S8.2
matrix_middle_top_SW: D9.2, S9.2
matrix_pinky_bottom_SW: D1.2, S1.2
matrix_pinky_home_SW: D2.2, S2.2
matrix_pinky_top_SW: D3.2, S3.2
matrix_ring_bottom_SW: D4.2, S4.2
matrix_ring_home_SW: D5.2, S5.2
matrix_ring_top_SW: D6.2, S6.2
thumb_far_thumb_SW: D18.2, S18.2
thumb_home_thumb_SW: D17.2, S17.2
thumb_near_thumb_SW: D16.2, S16.2

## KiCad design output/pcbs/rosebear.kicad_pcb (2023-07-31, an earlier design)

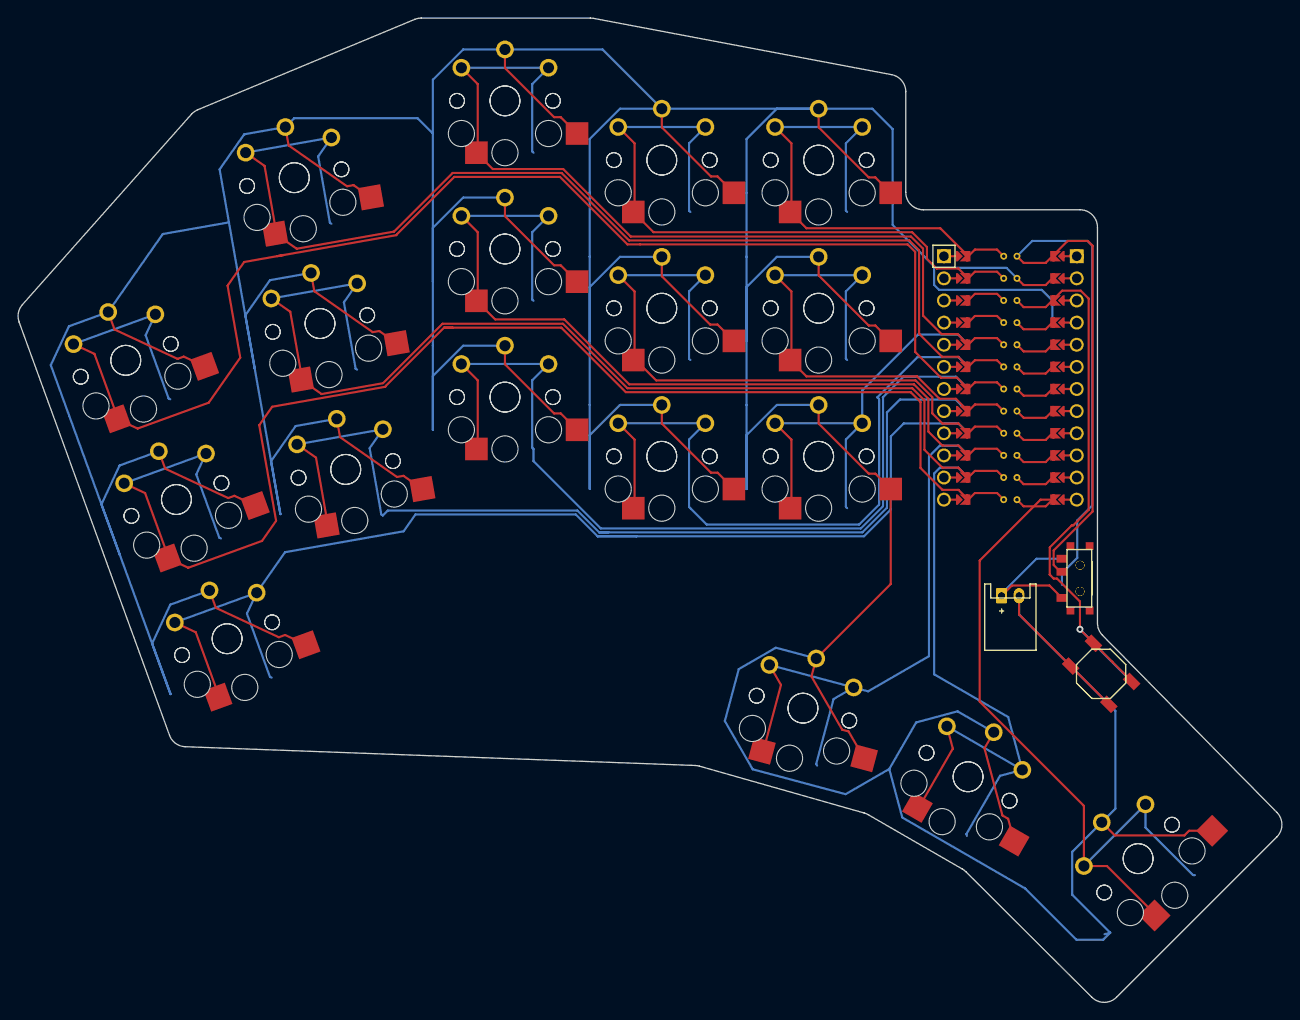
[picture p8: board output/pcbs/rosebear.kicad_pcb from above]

Board: 2 copper layers, 145.1 x 113.0 mm, 43 parts (0 on the bottom side), 22 nets.

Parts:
B1, B2: SW_TACT_ALPS_SKQGABE010
JST1, JST2: JST_PH_S2B-PH-K_02x2.00mm_Angled
MCU1: ProMicro
S1, S2, S3, S4, S5, S6, S7, S8, S9, S10, S11, S12, S13, S14, S15, S16, S17, S18, S19, S20, S21, S22, S23, S24, S25, S26, S27, S28, S29, S30, S31, S32, S33, S34, S35, S36: PG1350
T1, T2: SPDT_C128955

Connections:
Bplus: JST1.1, JST2.1, T1.1, T2.1
GND: B1.1, B2.1, JST1.2, JST2.2, MCU1.2, MCU1.21, MCU1.22, S1.2, S2.2, S3.2, S4.2, S5.2, S6.2, S7.2, S8.2, S9.2, S10.2, S11.2, S12.2, S13.2, S14.2, S15.2, S16.2, S17.2, S18.2, S19.2, S20.2, S21.2, S22.2, S23.2, S24.2, S25.2, S26.2, S27.2, S28.2, S29.2, S30.2, S31.2, S32.2, S33.2, S34.2, S35.2, S36.2
P0: MCU1.23, S12.1, S30.1
P1: MCU1.24, S15.1, S33.1
P2: MCU1.20, S9.1, S27.1
P3: MCU1.19, S6.1, S24.1
P4: MCU1.18, S3.1, S21.1
P5: MCU1.17, S14.1, S32.1
P6: MCU1.16, S11.1, S29.1
P7: MCU1.15, S8.1, S26.1
P8: MCU1.14, S5.1, S23.1
P9: MCU1.13, S2.1, S20.1
P10: MCU1.12, S18.1, S36.1
P14: MCU1.10, S16.1, S34.1
P15: MCU1.9, S1.1, S19.1
P16: MCU1.11, S17.1, S35.1
P18: MCU1.8, S4.1, S22.1
P19: MCU1.7, S7.1, S25.1
P20: MCU1.6, S10.1, S28.1
P21: MCU1.5, S13.1, S31.1
RAW: MCU1.1, T1.2, T2.2
RST: B1.2, B2.2, MCU1.3

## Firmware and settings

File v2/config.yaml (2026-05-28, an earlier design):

units:
  kx: 19
  ky: 19
  px: kx+2
  py: ky+2
points:
  zones:
    matrix:
      anchor:
        shift: [50, -100]
      key:
        padding: ky+2
        spread: kx+2
      columns:
        pinky:
          key:
            splay: 5
            col_net: COL0
          rows:
            top.led_in: LED_DIN
            top.led_out: LED_01
            home.led_in: LED_09
            home.led_out: LED_10
            bottom.led_in: LED_10
            bottom.led_out: LED_11
        ring:
          key:
            splay: -5
            spread: 1.08 kx
            stagger: 0.5 ky
            col_net: COL1
          rows:
            top.led_in: LED_01
            top.led_out: LED_02
            home.led_in: LED_08
            home.led_out: LED_09
            bottom.led_in: LED_11
            bottom.led_out: LED_12
        middle:
          key:
            splay: 0
            spread: 1.08 kx
            stagger: 5
            col_net: COL2
          rows:
            top.led_in: LED_02
            top.led_out: LED_03
            home.led_in: LED_07
            home.led_out: LED_08
            bottom.led_in: LED_12
            bottom.led_out: LED_13
        index:
          key:
            stagger: -0.4 ky
            col_net: COL3
          rows:
            top.led_in: LED_03
            top.led_out: LED_04
            home.led_in: LED_06
            home.led_out: LED_07
            bottom.led_in: LED_13
            bottom.led_out: LED_14
        inner:
          key:
            stagger: -0.2 ky
            col_net: COL4
          rows:
            top.led_in: LED_04
            top.led_out: LED_05
            home.led_in: LED_05
            home.led_out: LED_06
            bottom.led_in: LED_14
            bottom.led_out: LED_15
      rows:
        bottom:
          row_net: ROW2
        home:
          row_net: ROW1
        top:
          row_net: ROW0
    thumb:
      anchor:
        ref: matrix_inner_bottom
        shift: [-0.5 kx, -1.5 ky]
      columns:
        near:
          key:
            splay: -15
            col_net: COL5
            row_net: ROW2
            led_in: LED_15
            led_out: LED_16
        home:
          key:
            spread: 1.16 kx
            splay: -15
            rotate: 90
            width: 1.5 kx
            stagger: -0.1 kx
            col_net: COL5
            row_net: ROW1
            led_in: LED_16
            led_out: LED_17
        far:
          key:
            spread: 1.15 kx
            splay: -15
            stagger: -0.15 kx
            col_net: COL5
            row_net: ROW0
            led_in: LED_17
            led_out: LED_DOUT
      rows:
        thumb:
outlines:
  keys:
    - what: rectangle
      where: true
      size: [kx-0.5, ky-0.5]
  board:
    - what: polygon
      operation: stack
      points:
        - ref: matrix_pinky_bottom
          shift: [-0.45px, -1.0py]
        - ref: matrix_pinky_top
          shift: [-0.45px, -0.5py]
        - ref: matrix_pinky_top
          shift: [-0.45px, 0.5py]
        - ref: matrix_pinky_top
          shift: [-0.3px, 1.2py]
        - ref: matrix_middle_top
          shift: [-0.5px, 0.45py]
        - ref: matrix_middle_top
          shift: [0.5px, 0.45py]
        - ref: matrix_inner_top
          shift: [0.75px+22, 0.8py]
        - ref: matrix_inner_top
          shift: [0.75px+22, -3py]
        - ref: thumb_far_thumb
          shift: [1.5px, -0.1py]
      fillet: 8
  combo:
    - name: board
    - operation: subtract
      name: keys
pcbs:
  rosebear:
    outlines:
      main:
        outline: board
    footprints:
      switches:
        what: mx
        where: true
        params:
          keycaps: true
          reverse: false
          hotswap: true
          from: "{{col_net}}"
          to: "{{name}}_SW"
      diodes:
        what: sod123
        where: true
        params:
          side: F
          from: "{{name}}_SW"
          to: "{{row_net}}"
        adjust:
          shift: [0, -7]
      leds:
        what: sk6812mini_e
        where: true
        params:
          VDD: LED_VDD
          GND: GND
          din: "{{led_in}}"
          dout: "{{led_out}}"
      mcu:
        what: promicro
        where:
          ref: matrix_inner_top
          shift: [22, -25]
          rotate: 270
        params:
          RAW: RAW
          GND: GND
          RST: RST
          VCC: VCC
          P21: ROW0
          P20: ROW1
          P19: ROW2
          P18: COL0
          P15: COL1
          P14: COL2
          P16: COL3
          P10: COL4
          P1: COL5
          P0: LED_DATA_MCU
          P2: IH_TX_MCU
          P3: IH_RX_MCU
          P4: IH_DETECT_MCU
          P5: IH_SPARE_MCU
          P6: LED_ENABLE
          P7: BATTERY_SENSE
          P8: SPARE_0
          P9: SPARE_1
      led_data_resistor:
        what: resistor_0603
        where:
          ref: matrix_inner_top
          shift: [36, -11]
          rotate: 180
        params:
          side: F
          from: LED_DATA_MCU
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

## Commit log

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2026-08-23 Stand the finger connectors on the pod-facing edge; fix the LED's rotation
    Both halves put their ribbon connectors on the edge facing the pod -- the
    right of the left half, the left of the right half -- so the cables leave
    toward the middle of the keyboard instead of doubling back around the
    board. Turning a connector through a right angle turns the fan-in with
    it, and three things had to follow.
    The connector's angle now decides the fan-in's planarity. Two chords
    joining two disjoint arcs of a convex region never cross exactly when
    the matching reverses the boundary order, and it is the connector's
    rotation that fixes which end contact 1 sits at. The angle that points
    the cable off the boa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
2026-08-24 v3: place ribbon connectors by where their cables go, shrink the key boards
    Every connector now points its cable at the board it feeds. The pod link
    stands on the inboard edge level with the switches and is met by a bus; the
    finger board's thumb link sits below the innermost column facing down; the
    thumb board's connector sits above its keys facing up.
    Turning a connector decides which end of it contact 1 is at, so the pinouts
    follow: rows reverse on both hands, columns only on the left. The bus turns
    its corner one row per conductor -- diagonals straight onto the lanes cross
    every lane. BUS_STANDOFF keeps the first lane clear of the connector's own
    mounting-peg ground pads.
    Finger boards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
2026-08-24 v3: fix FFC cable mapping — every link was cross-wired end to end
    A same-side FFC between facing connectors joins contacts by position, and
    the facing turns one row around: pad 1 lands on pad N. Both ends of every
    ribbon assigned signal i to pad i, which no check could see — the combined
    view joins nets by name and nothing models the cable. The pod's two FFC
    connectors were also mounted with their cable openings toward the pod's
    centre, and the pod link's contact rows sat 4.5mm below the finger boards'.
    - from_end_signals: the from-end of each ribbon numbers its pads from the
    reversed signal list (pod for the pod links, finger for the thumb links)
    - pod_connector_angle flipped so the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
2026-08-24 v3: slope the fan band to the key stagger, and build LED-only
    The band above the finger keys was a flat slab held clear of the tallest
    column, wasting the whole ~25mm stagger over every other column. The exit
    line is now an ExitLine {y0, m}: finger_exit_line fits the tightest straight
    line that clears one constraint point per obstacle -- each column's top
    signal pad, each key's ground-stitch via (5.4mm higher than the pad; the
    flat design cleared these only by luck), and the LED chain's over-the-top
    column crossings, which climb to the taller neighbour's height. The whole
    band shears with the line, which preserves every planarity argument, and
    the flat clearance itself dropped from 13mm to w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
2026-08-25 v3: flatten the fan band and drop it onto the tallest column
    The sloped exit line was a mistake: it minimised slack over its constraint
    points, most of which sit on the short side columns, so it rode ~7mm high
    over the middle column -- the one place the eye (and the user) measures.
    Undo the slope entirely; the line is horizontal again and simply as low as
    the constraints allow.
    What actually lets it drop ~14mm:
    * LED column transitions no longer cross over the top of the columns. Both
    ends of a top transition attach on their east sides (west of every key,
    the key-below's socket ground hook climbs through the exit row), and the
    link threads the shared corridor and the eastern key's no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
2026-08-25 v3: stack the fan band per column so it hugs every column
    The flat exit line held all 16 band rows on one ladder fitted to the
    tallest column, so the six rows serving the inner and index columns --
    which turn off toward the connector before reaching the middle column --
    left ~8mm of empty air over the middle column's keycaps.
    Replace the shared line with per-column band groups: columns ordered
    nearest-the-connector-first, each group of rows sitting as low as that
    column's own top signal pads and ground-stitch vias allow, or one bus
    pitch above the previous group's top, whichever is farther out. Each
    column's escape channel now ends one bus gap short of its own group
    instead of on the shared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
2026-08-28 v3: emit the segmented outline, and fix what emitting it found
    The flex geometry existed and was tested but nothing wrote it out, so
    none of it had ever met KiCad. Emitting it turned up four real defects,
    each of which is now a test.
    Board gains `cuts: Vec2[][]` for interior Edge.Cuts contours, threaded
    through every construction site; `emit_panel` writes one closed polygon
    per cut, numbered from a range far clear of the outlines so a rigid
    board's file is unchanged by their existence. `flex_board.baml` turns a
    module into strips, cuts, parts and connectors, and `build_boards`
    dispatches to it on the new `flex` feature. `route.baml:enclose` never
    runs on that path -- on a segmented board th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
2026-08-28 v3: place the pod connector from the fan the ribbon actually needs
    pod_lanes() guesses half the ribbon plus one, and the connector was placed
    from that guess. The guess holds for the twenty-way direct-wired ribbon; the
    eleven-way matrix ribbon puts every leg on the same side of the fan, so the
    channel ran two lanes past where the connector sat and both outer lanes
    crossed the FFC's mounting pegs -- four nets shorted to ground.
    Lay the fan out twice. The guess only feeds the connector's x and the split
    only depends on y, so a fan built against the guessed position already knows
    its true half-width.
    Claude-Session: https://cl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
2026-08-28 v3: flex routing rules, as checks
    Five rules a folded board has to obey, none of which DRC can see -- KiCad has
    no idea which parts of this outline fold. They run over the routed boards
    rather than over the functions that build them, so a future router still
    answers to them.
    The one that needed a change was the pour. `board_zones` pours over the whole
    outline, which on a segmented board means a solid plane across every ligament
    and down every neck: a stiffener where the board is meant to give, and a crack
    starter at the cut edge that starts it. Under the matrix neither switch
    terminal is ground, so the only ground on a finger board is the two links'
    contacts and mounting pegs -- and both li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
2026-08-28 v3: cut and route the thumb cluster
    The cluster is not the shape `strips_of` cuts. Its three keys sit almost
    in a plane, splayed round the thumb's arc rather than stacked along a
    cylinder, and the only place it wants to fold is the one gap wide enough
    to put a serpentine in. So it is cut the way BastardKB cuts its five-key
    cluster: rigid islands joined by one neck, {near, home} | {far}, which
    sends two lines over the seam where the other cut would send three.
    Everything is stated in the cluster's own frame -- x along the near-to-far
    run, y across it -- where the islands are rectangles and `Strip`,
    `flex_ring` and `strip_neck` apply unchanged. `Frame.flip` makes one
    description serve both ha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
2026-09-26 v4: one hand-edited pod pin map, pod.json
    The pod's pins were spread across trackball.py (two maps of the same
    pins), validate.py, build_key_quotes.py, the v3 BAML header tables and a
    string-patched pinout.txt. pod.json now holds the module header, pin
    concession costs and the hand-chosen trackball and rgb groups.
    The seed stages its header and costs from pod.json and cannot take a
    fixed group's GPIO. The build reads the finished pod back into
    pod-pins.json, and renders pinout.txt and a full firmware-pinout.json
    from it. Validation and the RGB quote pod check against pod.json.
    All seven v4 boards are unchanged against a pre-refactor build. The RGB
    quote pod has the same footprints and nets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
2026-09-26 v4: docs match the key-tile decision; add design-status.md
    Record decisions and open questions in one place, mark the flex finger
    and flat thumb docs as paused reference, update LED power (module USB
    5V, ~300 mA cap), flag the Molex connector for replacement and the
    undersized chassis adapter placeholder.
2026-09-26 v4: power the LEDs from module USB 5V; swap to the JUSHUO FFC connector
    Drop the pod's separate J3 LED input and feed +5V from the module's 5V
    header pin, listed in pod.json's rgb group. Replace the Molex 200528-0240
    (MOQ 9,000) with the LCSC-stocked JUSHUO AFA07-S24FCA-00; the breakout
    grows to 36 x 33 mm. Both boards reroute DRC-clean and pass the audit.
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2026-09-28 v4: PROTOTYPE fix Skeletyl artefacts, rounded column ends, inner support, plate toggle
    Drop the smoothing that spiked thin walls, restore switch holes, one flat
    skirt per key, larger thumb window, quarter-round column ends inside an
    extended tray, solid inner wall joined to the thumbs, Cirque moved 8 mm
    out. Bottom plate checkbox; cam/caps/plate URL params for inspection.
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2026-09-28 v4: PROTOTYPE skeletyl floor ledge instead of feet, fix tray outline hull
    The feet reached toward the rim and were trimmed into fins. A 2 mm floor
    ledge now runs from the rim in under the column walls. The tray outline
    built its convex hulls with new CrossSection(points).hull(), whose fill
    rule dropped points, so back caps hung past the rim; it now uses a plain
    2D hull. The stats line also lists loose pieces and parts outside the rim
    by location, and ?only= / ?nocut=1 isolate Skeletyl parts for debugging.
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2026-09-28 v4: PROTOTYPE skeletyl bridged variants join column end walls in their lower half
    Replaces the bars between the key-frame flanges. No rim or lip; the base
    plate is flush with the walls.
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2026-09-28 v4: prototype thumb layout with wells, wider spacing and room from the finger columns; keycap clearance check
2026-09-28 v4: promote the swept Skeletyl chassis to the editor, edited through key layout parameters
    Finger columns take three key heights, stagger, X offset, sideways tilt and
    splay; thumb clusters take centre, angle, tilts, arc radius, key spacing and
    well. Handles drag key heights, stagger, cluster centres and cluster angle.
    The chassis is generated from the key poses and checked for seats, openings,
    tile and keycap clearance, loose pieces and keycap gaps. The Cirque pod
    replaces the trackball placeholder.
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2026-09-29 v4: plates sized from the switch seat, and nothing built into a tile pocket
    Plates are now 0.9 mm past the 15.8 mm seat (17.6 mm square) instead of keycap
    sized, so they no longer stick out past the swept ends; skirts, which the tile
    pockets would remove, are gone. Swept ends start past the end keys' tile
    pockets. Wall segments, joints and caps are built as separate tilted and
    vertical hulls so no hull reaches into a pocket on a rolled key. The thumb
    support and web are removed, the pod bracket is fixed to the plate corners,
    and the default thumb clusters move 3 mm toward the user to clear the fingers'
    front end. The checker fails when any part reaches into a tile pocket.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
2026-09-29 v4: swept ends follow each column's end, and a check for chassis built where a keycap goes
    The swept end's curve was a quadratic fit through all the column ends, pushed
    out until the round started past every tile pocket in plan. That left 5-10 mm
    of flat plate at most column ends, and the front round reached far enough
    forward that the 1.5u thumb key's room cut 74 mm³ out of the inner column.
    Now the curve runs parallel to each column's plate edge, as close in as the
    tile pocket and switch body allow (they must stay inside the round's hollow,
    not just short of it in plan), and never inside the switch seat. A smooth
    maximum joins the columns' lines. Flats are now 0.4-2.3 mm.
    New check: the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
2026-09-29 v4: cut the hex pattern off at the base strip on short walls
    Keys whose upright would be shorter than the wall width lose the strut
    below them, so the pinky column and extra thumb pair get the pattern too.
    End half hexagons are cut only where a cap closes the run's end. The wall
    check closes zero-width slits left by projection.
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2026-09-30 v4: PROTOTYPE finger tile rests: short feet under the back of each tile's side edges
    A tile goes up 4.3 mm in front of its place and slides back onto the feet,
    which sit under the socket. The bridges between columns stay 12 mm long.
    Only the index, middle and ring columns' top and home tiles fit this way:
    bottom-row tiles hit the front swept end and outer-column tiles the wall
    posts.
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2026-09-30 v4: walls stand outside the plate edges; catch small loose pieces
    The inner bottom post slot cut one of its tile's feet loose, and the
    loose-piece check missed it because it ignored pieces under 50 mm³. It
    now ignores only slivers under 0.5 mm³.
    Walls now stand wall_mm outside the plate edges, so the tile pockets stay
    inside them rather than running out through the wall. Every finger tile
    now slides onto its feet, including the outer columns', so tile_side_entry
    and the post slot are gone; the outer feet hang from the wall. Swept ends
    run on to the wall's face, the hex openings stop at the plate's
    underside, and the pod bracket reaches the wall's face.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
2026-10-01 Revert "v4: socket posts on the bottom plate hold the bottom row's socket end"
    This reverts commit ea40e797c52ba014622452937f69a13b469394b2.
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2026-10-01 v4: lids over the finger tiles' feet hold each tile edge in a slot
    The bottom row's feet are under the front of the tile, so pressing a switch
    in levered the socket end down about them. A lid from the plate to 0.2 mm
    above each foot stops the tile tipping. The seat test now skips edge rays
    that start inside both bodies, where the plate runs on into a bridge.
2026-10-01 v4: bottom-row lids beyond the feet, not over them, so no support fills a slot
    The lids over the feet left a 1.8 mm slot that a print on its base would fill
    with support. The bottom row's lids now run from 6.5 mm in front of the centre
    to the tile's front end, and its feet stop 1.5 mm short of them, so nothing is
    under a lid down to the bed. The other rows' feet are under the socket and
    need no lids.
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2026-10-10 v4: PROTOTYPE C64 breadbins, one per cluster (c64-clusters variant)
    The C64 builder now takes a list of bins, each built in its own plan
    rotation with its own deck plane, margins and bullnose. c64-clusters gives
    the fingers, the thumb row and the trackpad a tight bin each: 181 cm² in
    plan against 143 for skel-swept-thumbs and 311 for the single breadbin.
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2026-10-11 v4: PROTOTYPE shapes page: fresh manifold instance per build, coarser curved-deck loft
    Manifold objects were never freed, so a few curved builds exhausted wasm
    memory and every later switch failed (decompose: index out of bounds).
    The curved loft now uses fewer stations and section points (4.2 s to 1.8 s).
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2026-10-11 v4: rebuild in about 3 s instead of 11.5 s, with the same wiring and checks
    - Route the wires once per build, not once for the skirts and again for the checks.
    - Wire router (2.8 s to 1.1 s, same routes): legs and the joins between them are
    made once and shared; segment tests use a plan grid of the obstacles and skip
    any obstacle whose gap on one axis is past the wire's reach; caches key on
    shared points, not strings.
    - Checks test against each key's piece of the chassis (cut from its column's,
    cut from the whole once), not the whole chassis, for every probe and envelope.
    - Keycap rooms and switch holes are cut in one boolean, not two per key.
    - Skirt notches only from the wire segme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
2026-10-11 v4: loft the wall between the decks every millimetre where it fades out, so it no longer twists into a fan of slivers
2026-10-11 v4: PROTOTYPE ?plates=narrow: finger plates flat only 0.8 mm past the switch seat, falling at 60 degrees (?slope=) by up to 2 mm towards the well's wall, joins between in-line neighbours cut the same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
2026-10-11 v4: PROTOTYPE ?plates=facets: the room under the keys stops at the floor's underside, so it no longer cuts the well's wall away above the floor (the slot whose kinked edge looked jagged); the flat-ar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
2026-10-11 v4: editor: a remembered 'show edges' no longer crashes the page on load, before the first chassis has arrived
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2026-10-11 v4: PROTOTYPE ?plates=facets: where a neighbour's plane stands above a key's flat area (the ring and pinky columns), a sloping step between the two flat areas' edges replaces the notches
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2026-10-13 v4: PROTOTYPE ?hand: the DIP follows the PIP but straightens no further than straight (or its resting angle where pressing bent it back), so the top row's fingertips no longer hyperextend
2026-10-13 v4: PROTOTYPE ?hand: a Reset hand button puts the hand sliders back to their defaults
2026-10-13 v4: PROTOTYPE ?hand: anchor the hand on the middle home cap top through the key's own tilt, so reloading no longer walks the layout away
2026-10-13 v4: PROTOTYPE ?hand: fingers press with the MCP flexing while the PIP and DIP give (Jindrich et al. 2004's mean pattern, scaled by a slider); the readout gives the middle finger's key slope per row
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2026-10-13 v4: PROTOTYPE ?hand: work backwards from the keys: each column's keys lie on a line tilted from the plate and face square off it, the MCP and PIP are solved to reach each key, and the readout gives t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
2026-10-13 v4: PROTOTYPE ?hand: the 1.5u + 2x1u keys face square to the row and the step between rows, so the 1u row no longer runs into the 1.5u; the readout gives how far the press is off square; the step def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
2026-10-14 v4: PROTOTYPE ?hand: fingertips are a ball fixed to the last segment, resting on the paper at the measured print, and touch each key at the ball's lowest point along the press, so curled fingers pres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
2026-10-14 v4: PROTOTYPE ?hand: the thumb defaults (and Reset hand) to the closest fit to the Dactyl Manuform's thumb keys relative to the middle home key: sweep -23, abduction 14, twist 17, curl 14, IP -3, CMC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
2026-10-14 v4: PROTOTYPE ?hand: every hand default (and Reset hand) is the closest least-squares fit to the Dactyl Manuform's 18 keys relative to the middle home key: tent 15, roll 4, wrist 12, bend -2, curls 1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
2026-10-14 v4: PROTOTYPE ?hand: each finger column runs the way the fingertip travels from the bottom key to the top, seen from above (knuckle to fingertip pointed steeply down, so 4 degrees of roll turned the 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
2026-10-14 v4: PROTOTYPE ?hand: the inner column is reached by the arm carrying the hand sideways (square to the index column), not a turn at a guessed wrist pivot, plus the index turned at its knuckle (0 = par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
2026-10-14 v4: PROTOTYPE ?hand: basic and advanced settings; presets for the Dactyl fit and a natural layout; a rotation handle for the hand (on the board) or the thumb (at its CMC); the thumb row can curl the 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
    Basic: Start from Dactyl fit / Natural, the rotation handle (hand: roll,
    wrist, bend; thumb: sweep, abduction, twist), finger curl (all four
    together), key spacing (rows, inner column and thumb gaps together), thumb
    curl and the cluster. Everything else is under Advanced; the thumb's CMC
    press blend is hidden (fixed at 0: the Dactyl fit settles there).
    The thumb row: MCP and IP degrees per key (+ curls toward the near key,
    straightens t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
2026-10-14 v4: PROTOTYPE ?hand: declutter the sidebar: the readout is just Valid (with the height) or a Not valid list; shorter slider labels, headings and tooltips; drop UI how-to notes and the clearance discl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
2026-10-14 v4: PROTOTYPE measured keycaps: 18.5 mm square at the base tapering to 14 mm at the top, 11 mm high, 6 mm over the plate at rest, 3.5 mm travel (switch.keycap_top_mm; the editor and the keycap checks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
    Cherry-picked from 331fbe5 (worktree-breadbin-box). The 1.5u thumb home cap is assumed 28 x 18.5 x 11. The default-chassis and keycap-collision tests keep the keycap sizes the chassis was laid out for.
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2026-10-15 v4: PROTOTYPE ?hand: the test frame doesn't rock: pressing any keycap corner pushes along the switch, and where that line meets the floor now lands within the rails (1 mm in at least). Where one didn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
2026-10-15 v4: PROTOTYPE ?hand: the test frame is a space frame of tetrahedra: the keys joined by webs are one piece (the finger matrix, the thumb cluster), each held at its outer corners (those round it from a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
2026-10-15 v4: PROTOTYPE ?hand: the test frame stands each plate of webbed keys (the finger matrix, the thumb cluster) on legs at its outer corners only: those whose key has no neighbour across either of the co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
2026-10-16 v4: PROTOTYPE ?hand: the test frame's webs join the keys' facing walls (the ring's side, a wall thick, plate top to lip bottom), not their bare edges. Where one key sits well above its neighbour (the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
2026-10-16 v4: PROTOTYPE ?hand: "Show the thumb pressing it" animates the thumb onto the key it's shown on, over and over: its last 15 mm onto the key and back, the joints moving as the press settings have them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
    Co-Author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
2026-10-16 v4: PROTOTYPE ?hand: two press buttons under "Show the thumb pressing it", to switch between the two ways the thumb might press: "Swing at the base" (the thumb stiff, swinging at the CMC out from the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
2026-10-16 v4: PROTOTYPE ?hand: wrist height (Basic, mm: the thumb's CMC above the middle home key's top, square to it) replaces the reach mix: it's what you control, and the reach mix follows (mixFor: the heig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
2026-10-16 v4: PROTOTYPE ?hand: WIP, the presets aren't valid: the thumb's photographed poses fixed, and two errors in the last change. The assumed CMC's poses had the thumb 8–9 mm into the paper: the fit put e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
2026-10-16 v4: PROTOTYPE ?hand: the 1.5u + 2×1u cluster works again. Its 1u row went in under the hand by curling the thumb toward its pose under the hand (print 5); since the roll became a setting, each pose i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
2026-10-16 v4: PROTOTYPE ?hand: WIP, the Dactyl fit and 1.5u + 2×1u aren't valid: the thumb keys face straight up (as the paper did in the photos), square to the sweep both ways, and the thumb touches them with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
2026-10-16 v4: PROTOTYPE ?hand: the thumb no longer presses with its nail. The CMC fit (thumb_cmc.py) had put the knuckle dots on the side of the thumb away from the camera (95° and 105° off its line of sight),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
2026-10-16 v4: PROTOTYPE ?hand: the thumb keys move smoothly with the thumb settings. Found by sweeping each thumb setting in fine steps on both presets: (1) the press was made square to the reach with radial a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
2026-10-16 v4: the keycap room check measures where the keycap goes. The room that carves the chassis is a box the cap's base wide, well above it; the check counted any chassis it removed, so with the measured 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
2026-10-16 v4: PROTOTYPE ?hand: the test frame has a strut under each gap along its plates' outside edges, so the outer wall doesn't flex: a 2.4 mm post straight down from halfway down the web's outside wall (o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
2026-10-16 v4: PROTOTYPE ?hand: the thumb no longer goes through its key. Where it touches a key allowed for the key tilting across the bone only: the touching point was the print with the pad's radius taken sq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
2026-10-16 v4: PROTOTYPE ?hand: the test frame's outer walls are trusses, a web too thin to print is left out, and every preset is checked with the frame. Truss (replacing the vertical gap struts): under each o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
